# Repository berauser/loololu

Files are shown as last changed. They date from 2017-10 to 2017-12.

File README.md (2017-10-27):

# Dependencies

The project loolou depends on the avr-gcc and avrdude.

## Ubuntu

```
$ sudo apt-get install gcc-avr avrdude
```

# Build
## compile

```
$ make
```

## clean
```
$ make clean
```

## flash to attiny2313

```
# use default
# programmer: avrispv2
# usb device: /dev/ttyACM0
$ sudo make burn
```

```
# overwrite defaults
# AVRDUDE_PROGRAMMER override programmer type
# AVRDUDE_PORT overrides usb device
$ sudo make AVRDUDE_PROGRAMMER=avrispv2 AVRDUDE_PORT=/dev/ttyACM0 burn
```

## Useful links

* https://startingelectronics.org/tutorials/AVR-8-microcontrollers/ATtiny2313-tutorial/
* http://www.atmel.com/webdoc/avrlibcreferencemanual/index.html
* http://www.avr-tutorials.com/interrupts/avr-external-interrupt-c-programming

## Datasheet
### Attiny2313

* http://www.atmel.com/Images/Atmel-2543-AVR-ATtiny2313_Datasheet.pdf

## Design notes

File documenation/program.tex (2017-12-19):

\subsection{Spielmodis}

Die loolou Erweiterung hat vier verschiedene Modi zum Spielen. Diese k"onnen w"ahrend dem Spiel einfach "uber den Drucktaster am Oberteil der Spielbasis umgeschaltet werden.
Die vier roten LEDs neben dem Drucktaster zeigen dabei den aktuellen Modus an. \\
Die folgende Tabelle beschreibt die 4 verschiedenen Modi.

\vspace{1cm}
\begin{table}[ht]
	\centering

	\begin{tabular}{ c | p{8cm} } 
		% table header
		Modus								& Beschreibung \\ 
		\hline \hline
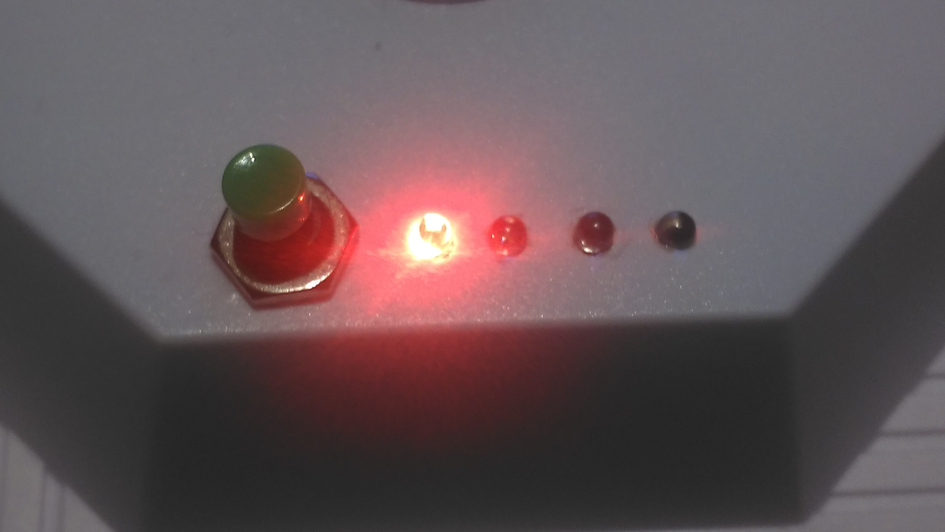
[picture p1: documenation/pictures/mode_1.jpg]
			& Einfacher Modus.\newline Looping Louie dreht sich so schnell wie beim originalen Spiel.  \\
		\hline
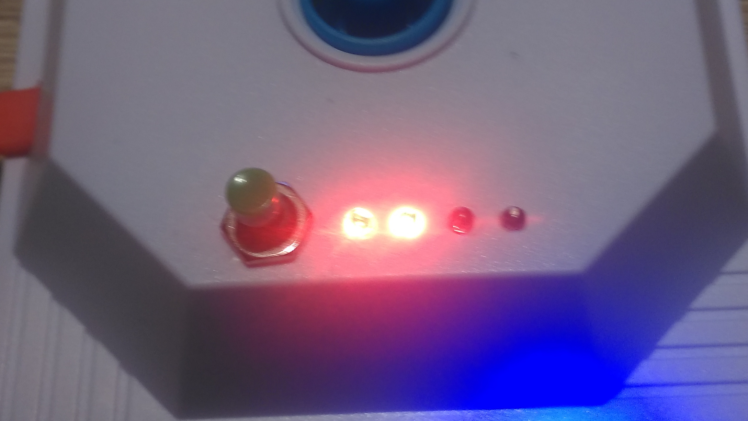
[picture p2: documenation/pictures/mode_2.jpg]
			& Schneller Modus.\newline Looping Louie dreht sich viel schneller als gewohnt. \\
		\hline
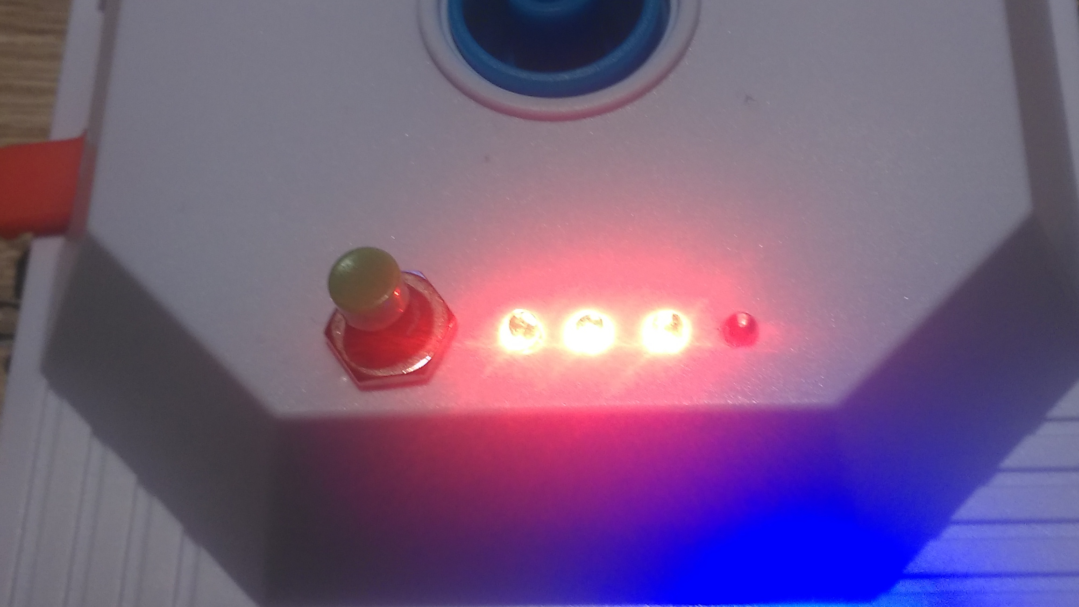
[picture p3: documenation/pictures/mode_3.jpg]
			& Zuf"alliger Modus.\newline Looping Louie "andert seine Gewschwindigkeit und bleibt auch mal stehen. \\
		\hline
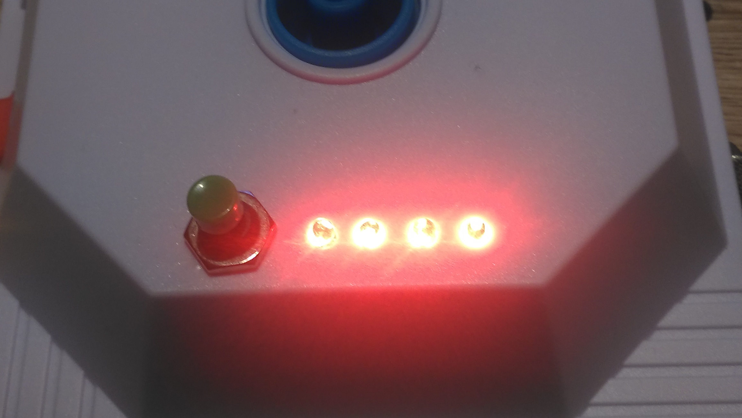
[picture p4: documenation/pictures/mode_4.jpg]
			& Zuf"alliger Modus mit R"uckw"artsgang.\newline Looping Louie "andert seine Geschwindigkeit und Richtung. \\
		\hline
	\end{tabular}

	\caption{Spielmodi}
	\label{table:mode}
\end{table}
\vspace{0.5cm}

\newpage
\subsection{Source code}

Der Source-Code von loolou ist ver"offentlich und kann heruntergeladen und selbst kompiliert werden.
Bitte beachten Sie die Lizenz von loolou. Zu finden ist diese im Kapitel ~\ref{section:licence} auf Seite ~\pageref{section:licence}.
\subsubsection{Github}\label{subsubsection:github}

Der Source-Code ist auf Github ver"offentlich und kann unter folgendem Link heruntergeladen werden. \\
\begin{center}\href{https://github.com/berauser/loolou}{https://github.com/berauser/loolou}\end{center}
\vspace{0.5cm}

\subsubsection{Defines}

Die defines sind in der Datei main.c definiert. Sie definieren die PINs und PORTs der LEDs, PWMs und des Drucktasters f"ur den ATTINY2313.
Ebenso werden hier die Timer-Delays und PWM-Frequenzen f"ur den Spielablauf definiert. Das folgende Listing (Listing ~\ref{lst:defines}) zeigt alle, f"ur den Spielablauf wichtigen, Defines. 

\vspace{0.5cm}
\begin{lstlisting}[caption={Defines},label=lst:defines]
// ********************************************************
// PWM values
// ********************************************************
#define PWM_OFF   0 // 0V ( OFF )
#define PWM_3V   85 // 3V ( (9V / 255) * 85 = 3V )
#define PWM_9V  255 // 9V

// ********************************************************
// PWM values
// ********************************************************
//
//   1000000Hz ( F_CPU )
//  --------------------- = 976,56 ( 0x3D0 )
//   1024 * 1Hz (1 sec)
#define TIMER_INT_DEPLAY 0x3D0

// ********************************************************
// Pin description
// ********************************************************
//
//		  attiny 2313
//           ---------------------
//  RESET   -| 1 (PA2)  (VCC) 20 |- VCC
//  LED5    -| 2 (PD0)  (PB7) 19 |- SCK
//  LED6    -| 3 (PD1)  (PB6) 18 |- MISO
//  LED7    -| 4 (PA1)  (PB5) 17 |- MOSI
//  LED8    -| 5 (PA0)  (PB4) 16 |- FORWARD
//  BUTTON  -| 6 (PD2)  (PB3) 15 |- BACKWARD
//  NC      -| 7 (PD3)  (PB2) 14 |- PWM
//  LED1    -| 8 (PD4)  (PB1) 13 |- LED4
//  LED2    -| 9 (PD5)  (PB0) 12 |- LED3
//  GND     -| 10(GND)  (PD6) 11 |- NC
//           --------------------
//

// *** LEDs ***********************************************
#define PIN_LED1 PD4
#define PIN_LED2 PD5
#define PIN_LED3 PB0
#define PIN_LED4 PB1
#define PIN_LED5 PD0
#define PIN_LED6 PD1
#define PIN_LED7 PA1
#define PIN_LED8 PA0

#define PORT_LED1 PORTD
#define PORT_LED2 PORTD
#define PORT_LED3 PORTB
#define PORT_LED4 PORTB
#define PORT_LED5 PORTD
#define PORT_LED6 PORTD
#define PORT_LED7 PORTA
#define PORT_LED8 PORTA

#define DDR_LED1 DDRD
#define DDR_LED2 DDRD
#define DDR_LED3 DDRB
#define DDR_LED4 DDRB
#define DDR_LED5 DDRD
#define DDR_LED6 DDRD
#define DDR_LED7 DDRA
#define DDR_LED8 DDRA

// *** DIRECTION / PWM ************************************
#define PIN_DIRECTION_FORWARD  PB4
#define PIN_DIRECTION_BACKWARD PB3
#define PIN_PWM                PB2

#define PORT_DIRECTION_FORWARD  PORTB
#define PORT_DIRECTION_BACKWARD PORTB
//#define PORT_PWM

#define DDR_DIRECTION_FORWARD  DDRB
#define DDR_DIRECTION_BACKWARD DDRB
#define DDR_PWM                DDRB

#define REGISTER_PWM  OCR0A
#define MODE_PWM      (1 << COM0A1) | (1 << WGM00)
#define CLOCK_PWM     (1 << CS01)

#define REGISTER_TIMER OCR1A
#define MODE_TIMERA    0x00
#define MODE_TIMERB    (1 << WGM12) | (1 << CS12) | (1 << CS10) // clk/1024

// *** BUTTON *********************************************
#define PIN_BUTTON  PD2
#define PORT_BUTTON PORTD
#define DDR_BUTTON  DDRD
#define EDGE_TYPE_BUTTON (1 << ISC01) // interrupt on falling egde
\end{lstlisting}
\vspace{0.5cm}

\subsubsection{Main-Methode}

Im Listing ~\ref{lst:main} ist die main-Funktion des Programmes. Diese initialisiert die Peripherie und springt dann in eine while-true-loop.
Die while-true-loop setzt in jeden Durchlauf die aktuelle Geschwindigkeit und schaltet die LEDs f"ur die Richtungsanzeige ein, beziehungsweise aus. Anschlie"send werden 250ms gewartet bis die n"achste LED f"ur die Richtungsanzeige eingeschaltet wird. 

\vspace{0.5cm}
\begin{lstlisting}[caption={Main-Method},label=lst:main]
// ****************************************************************************
// game
// ***************************************************************************/
int main(void) {

	init();
	setup();

	/* main loop */
	while (1) {
		/* all other uses interrupts */
		trigger_speed( speed );
		trigger_direction( direction );
		show_direction( direction );
		_delay_ms( 250 );
	}

	return 0;
}
\end{lstlisting}
\vspace{0.5cm}

\subsubsection{Init-Methode}

Die Methode init initialisert die GPIOs (General Porpuse Input/Output) des ATTINY.

\vspace{0.5cm}
\begin{lstlisting}[caption={Setup-Method},label=lst:setup]
// ****************************************************************************
// initialize gpio, set pin directions
// ***************************************************************************/
void init( void )
{
	// leds
	GPIO_init( DDR_LED5, PIN_LED5, OUTPUT ); // 1
	GPIO_init( DDR_LED6, PIN_LED6, OUTPUT ); // 2
	GPIO_init( DDR_LED7, PIN_LED7, OUTPUT ); // 3
	GPIO_init( DDR_LED8, PIN_LED8, OUTPUT ); // 4

	GPIO_init( DDR_LED1, PIN_LED1, OUTPUT ); // red
	GPIO_init( DDR_LED2, PIN_LED2, OUTPUT ); // blue
	GPIO_init( DDR_LED3, PIN_LED3, OUTPUT ); // green
	GPIO_init( DDR_LED4, PIN_LED4, OUTPUT ); // yellow

	// motor control
	GPIO_init( DDR_DIRECTION_BACKWARD, PIN_DIRECTION_BACKWARD, OUTPUT ); // backward
	GPIO_init( DDR_DIRECTION_FORWARD,  PIN_DIRECTION_FORWARD,  OUTPUT ); // forward
	GPIO_init( DDR_PWM, PIN_PWM, OUTPUT ); // PWM
	PWM_enable( MODE_PWM, CLOCK_PWM, REGISTER_PWM, PWM_OFF );

	// button
	GPIO_init( DDR_BUTTON, PIN_BUTTON, INPUT);
	GPIO_interrupt( PORT_BUTTON, PIN_BUTTON, INT0, EDGE_TYPE_BUTTON );

	// timer interrupt
	TIMER_enable( MODE_TIMERA, MODE_TIMERB );

	// Enable interrupts
	sei();
}
\end{lstlisting}
\vspace{0.5cm}

\subsubsection{Setup-Methode}

Die Setup-Methode initialisert das loolou-Programm mit den default-Werten.

\vspace{0.5cm}
\begin{lstlisting}[caption={Init-Method},label=lst:init]
// ****************************************************************************
// setup syStem with default values
// ***************************************************************************/
void init( void )
{
	// set initial values
	active_led  = LED1;
	mode        = M_NORMAL_FORWARD;
	speed       = PWM_3V;
	direction   = FORWARD;

	// show current mode
	show_mode();

	// set seed
	init_random( TCNT1L );

	// initial pwm
	trigger_speed( PWM_3V );

	// set initial timer delay
	TIMER_set( TIMER_INT_DEPLAY );
}
\end{lstlisting}
\vspace{0.5cm}

\subsubsection{Interrupt Service Routine}

Das Programm loolou implementiert zwei verschiedene Interrupt Service Routinen (ISR) - die ISR(INT0\_vect) und ISR(TIMER1\_COMPA\_vect). \\
Die ISR(INT0\_vect) wird bei einer fallenden Flanke am Drucktaster aufgerufen. In der ISR(INT0\_vect) wird der Modus des Spieles um eins hochgez"ahlt und neu ausgegeben. Anschlie"send wird der Timer zur"uckgesetzt und aufgerufen um die neue Geschwindigkeit und Spiel-Richtung zu setzen. \\
Die Interrupt Service Routine ISR(TIMER1\_COMPA\_vect) wird jede Sekunde aufgerufen und berechnet die Geschwindigkeit und die Spiel-Richtung neu.

\vspace{0.5cm}
\begin{lstlisting}[caption={Interrupt Service Routine},label=lst:isr]
// ****************************************************************************
// interrupt service routine
// ***************************************************************************/
ISR(INT0_vect)
{
	ADD_ONE_BETWEEN( mode, M_NORMAL_FORWARD, M_RANDOM_RANDOM );
	show_mode();

	/* reset timer, call ISR to change speed/direction immediately */
	TIMER_reset();
	TIMER1_COMPA_vect();
}

ISR(TIMER1_COMPA_vect)
{
	direction = calc_direction();
	speed = calc_speed();
}
\end{lstlisting}
\vspace{0.5cm}

\subsubsection{Calculate direction Methode}

Die Funktion calc\_direction gibt anhand des aktuellen Spielmodus die Spiel-Richtung zur"uck.
F"ur die drei Spielmodis \grqq{}Einfacher Modus\grqq{}, \grqq{}Schneller Modus\grqq{} und \grqq{}Zuf"alliger Modus\grqq{} wird immer die Spiel-Richtung \grqq{}forw"arts\grqq{} ausgeben.
Im Spielmodus \grqq{}Zuf"alliger Modus mit R"uckw"artsgang\grqq{} wird anhand einer Zufallszahl die Spiel-Richtung berechnet. In diesem Modus wird etwa 10\% \grqq{}r"uckw"arts\grqq{} und etwa 90\% \grqq{}forw"arts\grqq{} zur"uckgegeben.

\vspace{0.5cm}
\begin{lstlisting}[caption={Calculate direction},label=lst:calcdirection]
// ****************************************************************************
// calculates a new direction
// ***************************************************************************/
GameDirection calc_direction( void )
{
	switch( mode )
	{
		case M_NORMAL_FORWARD:
		case M_FAST_FORWARD:
		case M_RANDOM_FORWARD:
		default:
			return FORWARD;
			break;
		case M_RANDOM_RANDOM:
			return ( (get_random_between( 0, 10 ) == 0) ? BACKWARD : FORWARD ); /* 10% backward : 90% forward */
			break;
	}
}
\end{lstlisting}
\vspace{0.5cm}

\subsubsection{Calculate speed Methode}

Die Funktion calculate\_speed gitb anhand des Spielmodus die berechnete Geschwindigkeit zur"uck.
Im Modus \grqq{}Einfacher Modus\grqq{} wird immer der PWM-Wert f"ur 3V und im Modus \grqq{}Schneller Modus\grqq{} der PWM-Wert f"ur 9V zur"uckgeliefert.
In den Spielmodis \grqq{}Zuf"alliger Modus\grqq{} und \grqq{}Zuf"alliger Modus mit R"uckw"artsgang\grqq{} wird die Geschwindigkeit anhand zweier Zufallszahlen berechnet.
Dabei wird die erste Zufallszahl f"ur die grobe Einordnung der Geschwindigkeit verwendet und die zweite Zufallszahl f"ur die exakten PWM-Wert, der dann auch zur"uckgegeben wird. Die erste Zufallszahl ist in dieser BErechnung notwendig um gr"o"sere Spr"unge zwischen den Geschwindigkeiten zu reduzieren. 
Die Werte sind wie folgt aufgeteilt: Etwa 10\% zwischen 0.0V und \~{}3.5V, etwa 70\% zwischen \~{}3.5V und \~{}7.0V, sowie 20\% zwischen \~{}7.0V und \~{}9.0V. 

\vspace{0.5cm}
\begin{lstlisting}[caption={Calculate Speed},label=lst:calcspeed]
// ****************************************************************************
// calculates a new speed
// ***************************************************************************/
uint8_t calc_speed( void )
{
	switch( mode )
	{
	case M_NORMAL_FORWARD:
	default:
		return PWM_3V;
		break;
	case M_FAST_FORWARD:
		return PWM_9V;
		break;
	case M_RANDOM_FORWARD:
	case M_RANDOM_RANDOM:
	{
		/*
		 * Calculate speed in 25 steps.
		 * 0 = 0V, ...,  25 = ~9V
		 *
		 * For a better and faster playing pleasure,
		 * a probability of
		 * 10% values between   0V and 3,5V and
		 * 70% values between 3,5V and 6,0V is selected.
		 * 20% values between 7,0V and 9,0V is selected.
		 */
		static uint8_t r = 0;
		r = get_random_between( 0, 10 );
		if ( r == 0 )
		{ /* 20% slow ( 0V - ~3,5V ) */
			return get_random_between(  0, 100 );
		}
		else if ( r == 1 || r == 2 )
		{ /* 20% very fast /~7,0V - 9,0V */
			return get_random_between( 201, 255);
		}
		else
		{ /* 70% fast ( ~3,5V - ~7,0V ) */
			return get_random_between( 101, 200 );
		}
	}
		break;

	}
}
\end{lstlisting}
\vspace{0.5cm}

\subsection{Kompilieren des Sourcecodes}
\subsubsection{Abh"angigkeiten an das Buildsystem}

Um den C-Sourcecode f"ur den ATTINY2313 zu "ubersetzen werden einige wenige Anfoderungen an das Buildsystem gestellt.
Es wir lediglich die AVR-Toolchain (avr-gcc) und ein Programmer f"ur Atmel-Mikrocontroller ben"otigt (avrdude).
Um die Dokumentation zu erstellen wird zus"atzlich ein LaTeX-Kompiler ben"otigt, unter Ubuntu oder Debian bietet sich hier zum Beispiel texlive an.\\
\\
F"ur Ubuntu und Debian k"onnen die folgenden Befehle, zum installieren der Abh"angigkeiten, verwendet werden.

\vspace{0.5cm}
\begin{lstlisting}[caption={Build dependencies},language=sh,label=lst:builddep]
# install avr toolchain and avr programmer
sudo apt-get install gcc-avr avrdude
# install LaTeX-Compiler
sudo apt-get install texlive-full
\end{lstlisting}
\vspace{0.5cm}

\subsubsection{Kompilieren}

Das Kompilieren des C-Sourcecodes durch einen einfachen Make-Aufruf angesto"sen werden.
Dazu muss im Root-Verzeichniss des Sourcecodes folgender Befehl eingegeben werden.

\vspace{0.5cm}
\begin{lstlisting}[caption={Compile},language=sh,label=lst:makeall]
# compile loolou
make
\end{lstlisting}
\vspace{0.5cm}

\subsubsection{Aufr"aumen}

Um die Kompilierten Source wieder zu l"oschen kann der folgende Befehl verwendet werden.

\vspace{0.5cm}
\begin{lstlisting}[caption={Clean},language=sh,label=lst:makeclean]
# clean loolou sources
make clean
\end{lstlisting}
\vspace{0.5cm}

\subsubsection{Erstellen der Dokumentation}

Das erstellen der Dokumentation kann ebenso wie das kompilieren des Sourcecodes durch einen Make-Aufruf ausgef"uhrt werden.
Dazu f"ugt man das Schl"usselwort \grqq{}doc\grqq{} dem \grqq{}make\grqq{} an.

\vspace{0.5cm}
\begin{lstlisting}[caption={Create documentation},language=sh,label=lst:builddoc]
# create documenation
make doc
# clean documenation
make doc-clean
\end{lstlisting}
\vspace{0.5cm}

\subsection{Wie der Attiny2313 programmiert wird}
\subsubsection{Programming}

Ebenso wie das Kompilieren der Source kann der Attiny mittels eines vordefinierten Make-Aufrufs programmiert werden.
Dies kann "uber den Befehl \grqq{}make burn\grqq{} ausgef"uhrt werden.
Mittels den Variablen \textbf{AVRDUDE\_PROGRAMMER} und \textbf{AVRDUDE\_PORT} kann das Device und der Programmer-Typ definiert werden.
Die Default-Einstellungen sind \textbf{avrispv2} f"ur den Typ des Programmers und \textbf{/dev/ttyAMC0} f"ur das Device.
Der Typ des Programmers kann der Dokumentation des Programmers entnommen werden. \\
\\
\textbf{Achtung: Sollte der Programmer eine eigene Stromversorgung f"ur den Attiny haben, dann darf der 9V Stromanschluss des Looping Louie nicht angeschlossen werden}, wenn das Programmieren "uber die eingebaute Programmier-Schnittstelle (J1) stattfindet. Andernfalls kann der Programmer besch"adigt werden.

\vspace{0.5cm}
\begin{lstlisting}[caption={Programming},language=sh,label=lst:makeburn]
# flash the attiny (using default values)
make burn
# or
make AVRDUDE_PROGRAMMER=avrispv2 AVRDUDE_PORT=/dev/ttyAMC0 burn
# AVRDUDE_PROGRAMMER define programmer type
# AVRDUDE_PORT define programmer device
\end{lstlisting}
\vspace{0.5cm}

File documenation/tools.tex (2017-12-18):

F"ur den Umbau von Looping Louie werden diverse Werkzeuge ben"otigt. Diese sind in Tablle ~\ref{table:tools} aufgelistet.

\vspace{1cm}
\begin{table}[ht]
	\centering

	\begin{tabular}{ c p{8cm} } 
		% table header
		\hline \hline
			& Schraubenzieher (Kreuzschlitz) \\
			& Akkuschrauber                  \\
			& Bohrer (3/5/7/8mm)             \\
			& B"ugels"age                    \\
			& Feile                          \\
			& Zange                          \\
			& Seitenschneider                \\
			& L"otkolben                     \\
		\hline \hline
	\end{tabular}

	\caption{Werkzeuge}
	\label{table:tools}
\end{table}
\vspace{0.5cm}

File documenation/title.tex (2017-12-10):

\maketitle
\vspace{3cm}
\begin{figure}[!ht]
	\centering
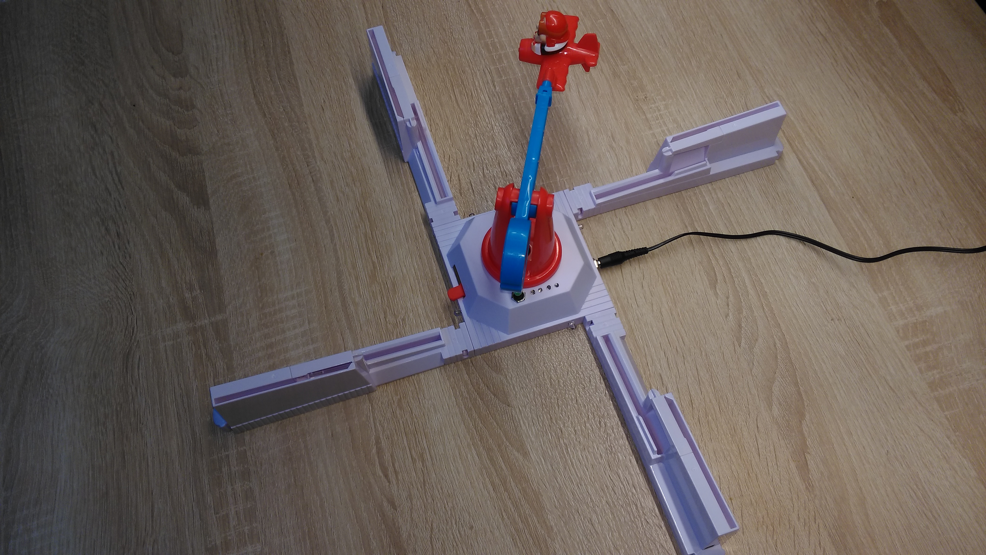
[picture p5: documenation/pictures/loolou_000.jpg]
  	
	\caption{Looping Louie mit loolou Erweiterung}
	\label{fig:loolou}
\end{figure}

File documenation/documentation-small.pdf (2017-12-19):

# loolou

Looping Louie Erweiterung

Benjamin Rauser

19. Dezember 2017

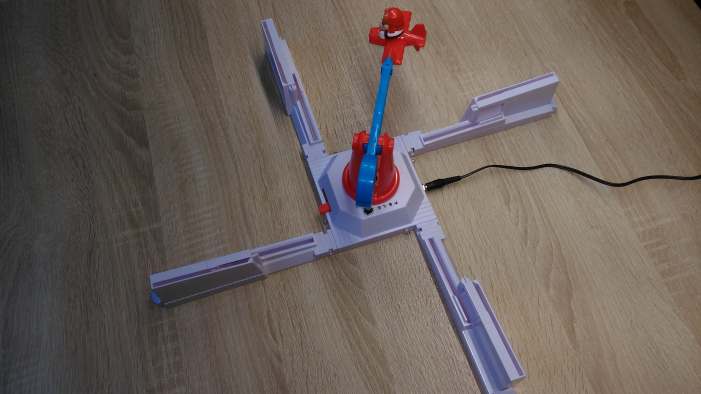
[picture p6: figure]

Abbildung 1: Looping Louie mit loolou Erweiterung

1

### Inhaltsverzeichnis

1. Motivation | 3
2. Werkzeug | 4
3. Hinweise | 4
4. Changelog | 5
5. Anleitung | 6
6. Programm | 19
7. Komponenten | 28
8. Lizenz | 30
9. Haftungsausschluss | 30
10.Anhang | 32
A. Layout | 33
B. Schaltplan | 34
C. Template | 35

2

### 1. Motivation

Intrinsisch

3

### 2. Werkzeug

Fur den Umbau von Looping Louie werden diverse Werkzeuge ben ¨ | ötigt. Diese sind in Tablle 1
aufgelistet.

Schraubenzieher (Kreuzschlitz) Akkuschrauber
Bohrer (3/5/7/8mm)
Bugels ¨ äge
Feile
Zange
Seitenschneider
Lötkolben

Tabelle 1: Werkzeuge

### 3. Hinweise

### 3.1. Revision 1

- Das Loch fur den Drucktaster und der Befestigungsschraube sind zu klein. D ¨ | iese sollte vorsichtig
aufgebohrt werden.

4

### 4. Changelog

### 4.1. Revision 1

- Erstellen des Schaltplanes.
- Erstellen des C-Quellcodes.
- Erstellen des Platinen-Layouts.
- Erstellen der Dokumentation.
- Hinzufugen von Fotos. ¨

5

### 5. Anleitung

### 5.1. Spielbasis

Zeitaufwand: 8h

Als erstes widmen wir uns der Spielbasis, zu sehen in Abbildung 2. Sie muss im ersten Schritt zerlegt und angepasst werden, um Platz fur die Platine zu schaffen. ¨

Dazu entfernen wir als erstes die 7 Schrauben an der Unterseite.
Die ersten 5 Schrauben sind mit bloßem Auge von aussen sichtbar. Die letzten zwei Schrauben sind nach dem öffnen des Batteriefaches zu sehen.

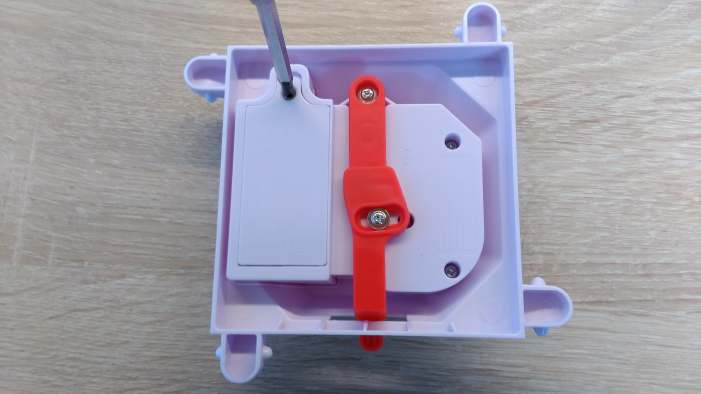
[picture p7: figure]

Abbildung 2: Spielbasis - Unterseite aufschrauben

Abbildung 3 zeigt die Spielbasis nach dem entfernen der 7 Schrauben.

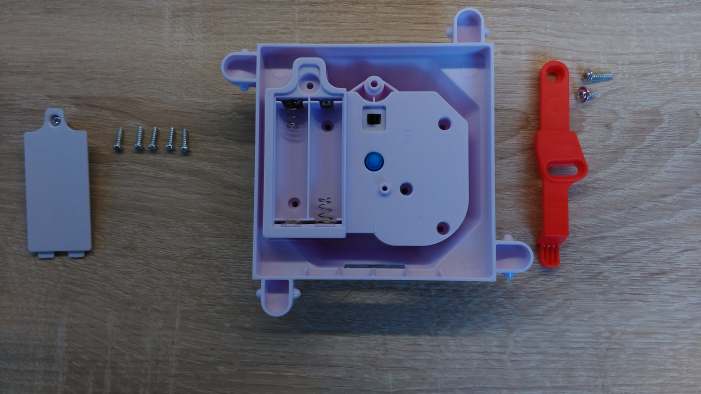
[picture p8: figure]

Abbildung 3: Spielbasis - geöffnet

6

Anschließend muss die Spielbasis geöffnet werden. Dazu zieht man das Innenteil der Spielbasis heraus. Zu sehen ist nun das Getriebe, der Motor und der Stromschalter (siehe Abbildung 4 und 5).

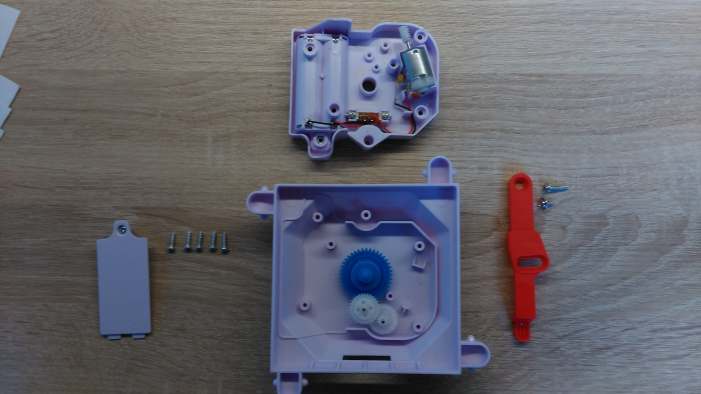
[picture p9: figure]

Abbildung 4: Spielbasis - geöffnet

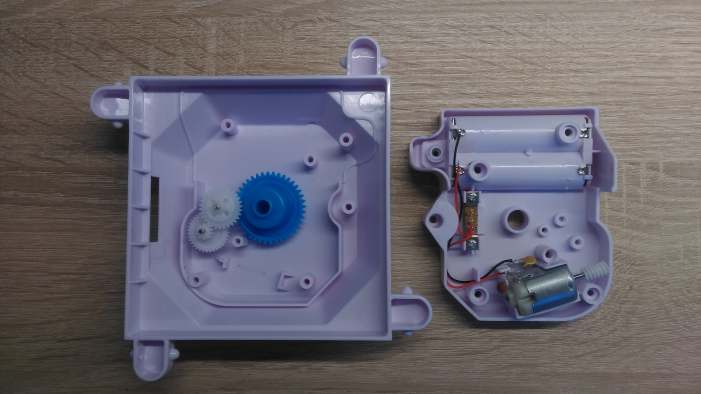
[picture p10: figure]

Abbildung 5: Spielbasis - Abdeckung

Nun muss der Motor, der Stromschalter und die Batteriekontakte entfernt werden.
Am besten löst man hierfur zuerst die Stromkabel, mit einem L ¨ | ötkolben, von den Batteriekontakten.
Anschließend kann der Motor ganz einfach herausgezogen und der Stromschalter mittels eines Schraubenziehers entfernt werden. Danach können die Batteriekontakte mit einer Zange herausgezogen werden. Abbildung 6 zeigt die Abdeckung der Spielbasis ohne Motor, Stromschalter und Batteriekontakte.

Als nächstes muss Platz fur die Platine geschaffen werden. ¨
Dazu bohrt man an den 4 Ecken des Batteriefaches jeweils ein Loch und sägt mit einer Säge am Rand

7

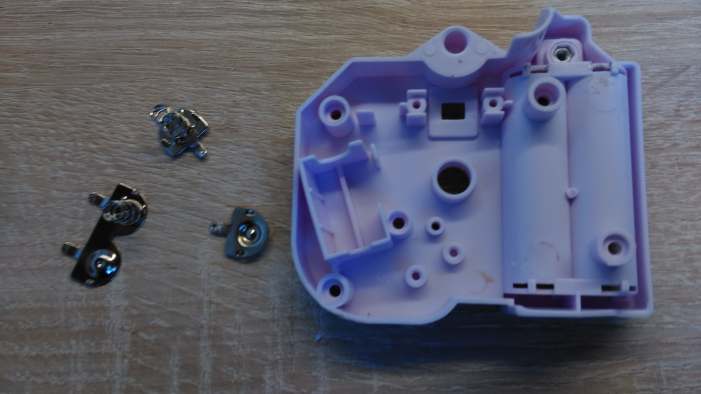
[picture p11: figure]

Abbildung 6: Spielbasis - Unterseite Abdeckung ohne Motor und Batteriekontakten

des Batteriefaches entlang (zu sehen in Abbildung 7).
Achte an dieser Stelle besonders auf das Gehäuse - Es sollte nicht brechen bzw. es sollte nicht weiter als die Umrandung des Batteriefach gesägt werden. Ansonsten sieht man beim späteren Zusammenbau
der Spielbasis die Schnitte der Säge. Ebenso sollten keine Gewinde fur die Schrauben abges ¨ | ägt werden,
mit Ausnahme der Gewinde im Batteriefach. Fur die feineren Arbeiten kann eine Feile benutzt werden. ¨ Anschlieend muss in den herausstehenden Seiten jeweils eine Ecke herausgefeilt werden (Gut zu sehen in der Abbildung 8). Diese werden später benötigt um die Stromkabel fur die LEDs und des Netzteils ¨ aus der Spielbasis herauszufuhren. ¨

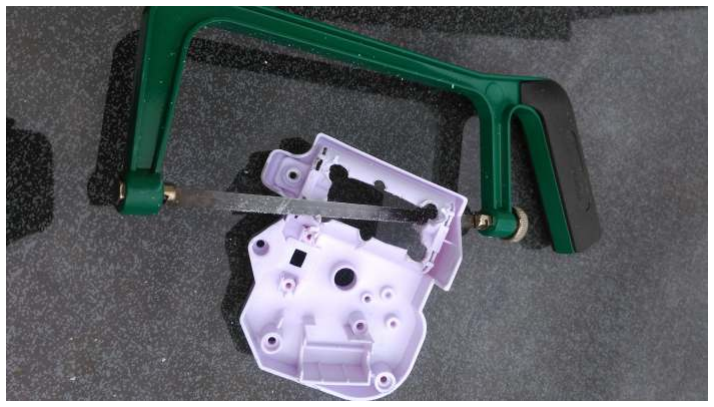
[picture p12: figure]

Abbildung 7: Spielbasis - Unterseite beim Aussägen

Abbildung 8 zeigt die fertig vorbereitete Unterseite der Spielbasis. Gut zu sehen sind hier die
abgefeilten Ecken fur die Stromkabel und das ausges ¨ | ägte Batteriefach. Wichtig an dieser Stelle ist
auch, dass das Batteriefach vollstäntig entfernt und bis auf den letzten Millimeter abgefeilt wurde. Ansonsten kann es vorkommen, dass das Gehäuse beim späteren Zusammenbau nicht richtig schließt.

8

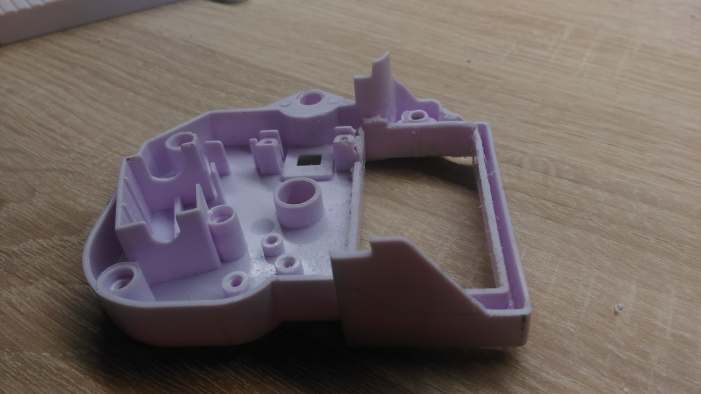
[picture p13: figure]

Abbildung 8: Spielbasis - Unterseite ausgesägt und geschliffen

Nun kann die Unterseite der Spielbasis zur Seite gelegt werden. Es folgt die Vorbereitung der Oberseite.
Als erstes sollte hier das Gewinde im linken oberen Eck (siehe Abbildung 9) mit einem Bohrer entfernt werden. Dieses Gewinde ist der Platine im Weg und muss daher entfernt werden. Achte hierbei darauf das nicht durch das Oberteil gebohrt wird, lasse lieber ein bis zwei Millimeter uberstehen. ¨

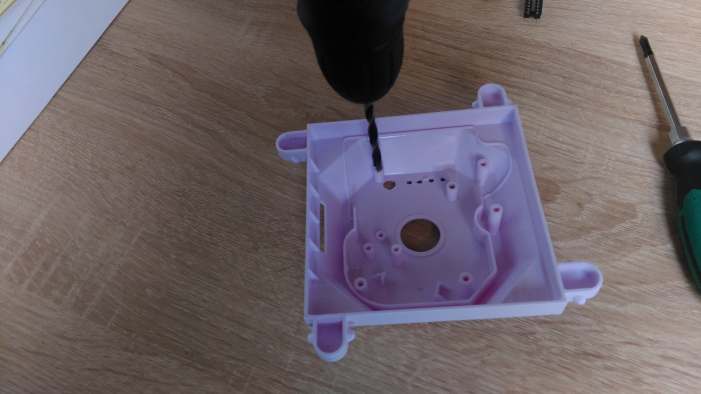
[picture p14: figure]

Abbildung 9: Spielbasis - Oberseite mit Gewinde das entfernt werden muss

Als nächstes schneidet man zuerst die Schablonen (siehe Anhang 10) aus. Diese werden benötigt
um die Löcher fur die LEDs, den Taster und den Stromanschluß richtig zu positionie ¨ | ren. Abbildung
10 zeigt die Schablonen und das fertig Vorbereitete Gehäuse.

Im nächsten Schritt nimmt man den große ausgeschnitten Teil der Schablone und legt ihn auf die

9

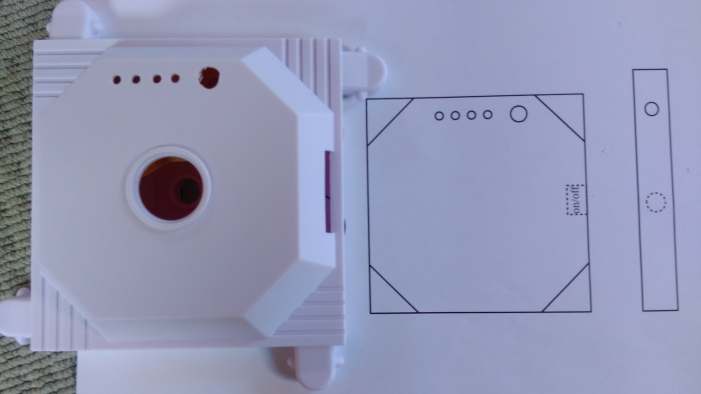
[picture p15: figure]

Abbildung 10: Schablonen und Oberteil der Spielbasis

Oberseite der Spielbasis. Man sollte hier darauf achten dass die Schrift “on/off“ uber dem AN/AUS- ¨ Schalter der Spielbasis liegt (zu sehen in Abbildung 11). Anschließend können zuerst mit einem spitzen Gegenstand (zum Beispiel einem Bohrer) die Löcher auf dem Oberteil der Spielbasis angekörnt werden.
Die kleinen Löcher, fur die LEDs, werden nun mit einem 3mm-Bohrer durchbohrt. Im Anschl ¨ | uss wird
das Loch fur den Drucktaster mit einem 7mm-Bohrer in das Oberteil gebohrt. Abb ¨ | ildung 11 zeigt
die gebohrten Löcher in dem Oberteil der Spielbasis. Zu sehen ist hier auch dass die Löcher auf der rechten Seite, vom AN/AUS-Schalter aus gesehen, liegen.

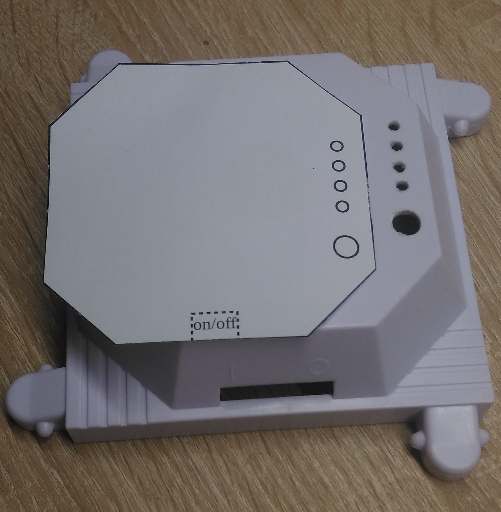
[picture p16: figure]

Abbildung 11: Spielbasis - Gebohrte Löcher fur die LEDs und den Taster im Oberteil ¨

10

Nun nimmt man das kleine rechteckige Teil der Schablone und körnt damit an jeder der 4 Seiten
das Loch fur die 5mm großen LEDs an (Kreis mit durchgezogener Linie). Dabei muss der ¨ | Kreis mit
der durchgezogenen Linie zu dem Verbindungsstuck, f ¨ | ur die Arme des Looping Louie, zeigen (zu sehen ¨
in Abbildung 12). Der gestrichelte Kreis ist fur den Stromanschluss. Dieser wird auf der, dem des ¨
AN/AUS-Schalter gegebuberliegenden Seite, gebohrt (zu sehen in Abbildung 12). Die L ¨ | öcher fur die ¨
LEDs werden mit einem Bohrer der Stärke von 5mm und das Loch fur den Stromanschluss mit einen ¨ 7mm großen Bohrer gebohrt.

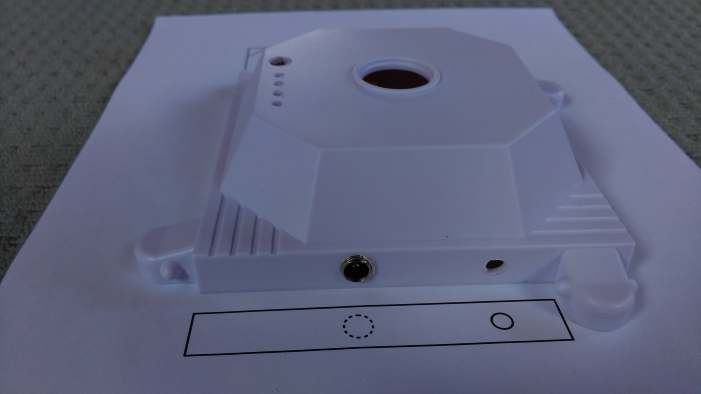
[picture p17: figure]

Abbildung 12: Spielbasis - Mit gebohrten Löchern in der Seite des Oberteils

Zum Abschluss können nun noch alle LEDs, der Drucktaster und der Stromanschluss in die Spielbasis gesteckt werden. Sollte hier noch etwas klemmen kann an dieser Stelle noch leicht nachgearbeitet werden.

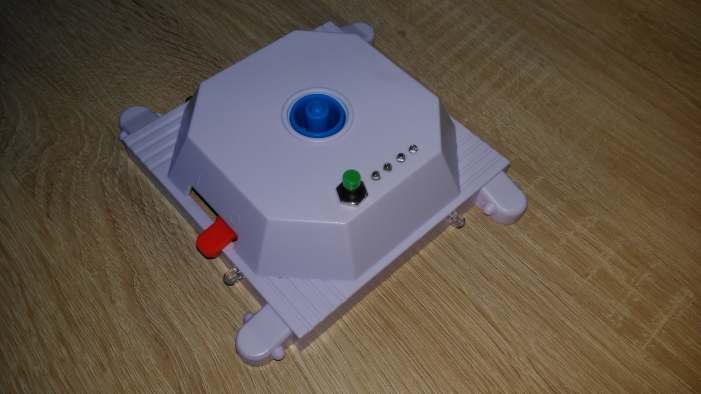
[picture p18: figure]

Abbildung 13: Spielbasis - Mit gesteckten LEDs, dem Drucktaster und dem Stromanschluss

11

Die Abbildung 13 zeigt die Spielbasis mit den gesteckten LEDs, dem Drucktaster und dem Stromanschluss. Die Bauteile können nun wieder aus der Spielbasis entfernt und zur Seite gelegt werden.

12

### 5.2. Platine

Nun widmen wir uns der Platine - dem Herzstuck der Erweiterung von Looping Louie. Zu sehen ist ¨ diese in den Abbildungen 14 (a) und (b).

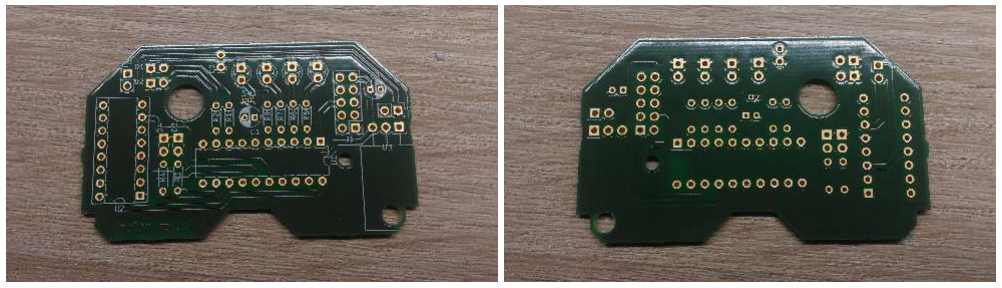
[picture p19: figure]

(a) Oberseite | (b) Unterseite

Abbildung 14: Originale Platine - Revision 1

Auf der Platine sind unteranderem ein kleiner Microcontroller (ATTINY2313), ein Treiberbaustein, ein Festspannungsregler sowie diverse LEDs und Widerstände verbaut. Der Schaltplan 10 und das Platinen-Layout 10 kann im Anhang gefunden werden. Die Referenzen der Bauteile können der Tabelle 4 entnommen werden.

Am einfachsten beginnt man an dieser Stelle mit den IC-Sockeln (U1 und U2), sowie dem Festspan-
nungsregler (U3). Im Anschluss kann der 10polige Wannenstecker (J1), fur den Programmer, aufgel ¨ | ötet
werden, dieser ist optional und wird nur benötigt wenn man den Attiny zum programmieren nicht herausnehmen möchte. Nachdem die IC-Sockel und der Festspannungsregler aufgelötet wurden, können die Widerstände (R1-R8) und die Kondensatoren (C1-C3) aufgelötet werden. Die Abbildung 15 zeigt die Platinen nach dem auflöten der Widerstände, der Kondensatoren, dem Festspannungsregler und den IC-Sockeln.

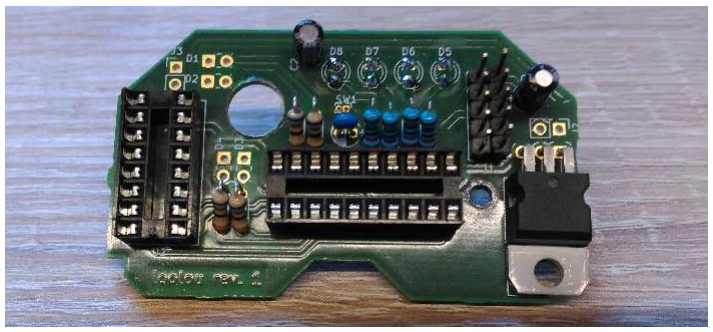
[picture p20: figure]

Abbildung 15: Platine mit aufgelöteten Widerständen und IC-Sockel

13

Nachdem nun die IC-Sockel (U1,U2), der Festspannungsregler (U3), die Widerstände (R1-R8) und die Kondensatoren (C1-C3) aufgelötet wurden, sollten die LEDs (D5-D8) aufgelötet werden. Dazu steckt man diese einzeln, von innen, in das Oberteil der Spielbasis und schraubt dann die Platine in
den dafur vorgesehenen Platz im Oberteil der Spielbasis. Wie die Platine ¨ | in das Oberteil der Spielbasis
geschraubt wird zeigt die Abbildung 16
Nachdem nun die LEDs in die Spielbasis gesteckt und die Drähte der LEDs (D5-D8) durch die dafur ¨
vorgsehenen Löcher gefuhrt wurden, k ¨ | önnen diese an der Platine festgelötet werden. Achte an dieser
Stelle darauf das die LEDs richtig gepolt sind, ansonsten mussen diese sp ¨ | äter wieder entfernt und neu
aufgelötet werden.

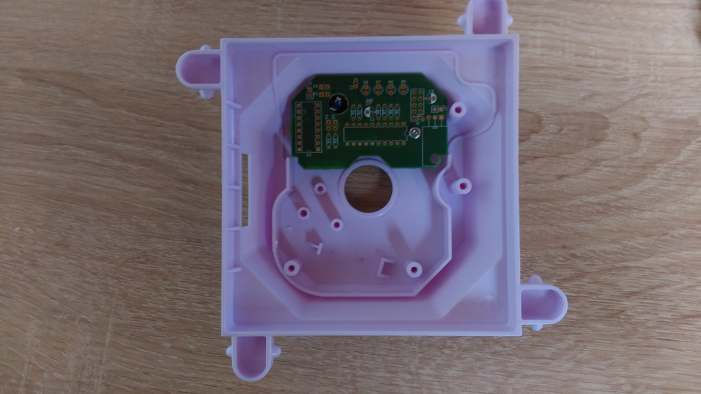
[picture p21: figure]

Abbildung 16: Platine festgeschraubt im Oberteil der Spielbasis

Nachdem nun auch die LEDs D5 bis D8 aufgelötet sind kann die Platine nun wieder aus der Spielbasis herausgenommen werden. Die Abbildung 17 zeigt die Platine mit den festgelöteten LEDs (D5-D8). Es empfiehlt sich an dieser Stelle die bisher festgelöteten Bauteile und die Lötstellen mit einem Durch-
gangsprufer zu testen, um kalte L ¨ | ötstellen und verpolte LEDs rechtzeitig zu erkennen.

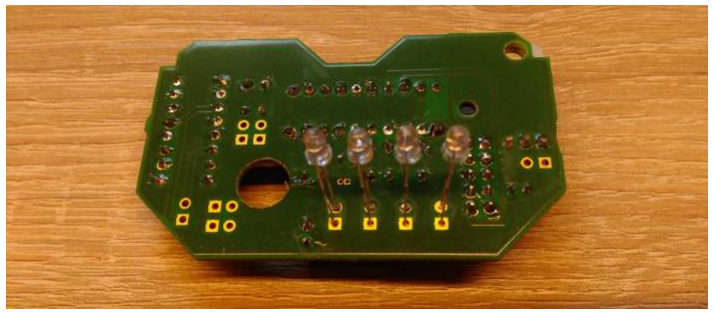
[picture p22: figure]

Abbildung 17: Platine mit LEDs auf der Unterseite

14

An dieser Stelle sollten die Litzen fur die restlichen LEDs (D1-D4), den Drucktaster (SW1), den ¨ Hohlstecker-Buchse (J2) und den Motor vorbereitet werden. Die Länge der Litzen kann einfach der Tabelle 2 entnommen werden. Es werden jeweils eine rote und eine schwarze Litze benötigt.

Reference | Description | Length
D1 | LED1, 5mm | 9cm
D2 | LED2, 5mm | 13cm
D3 | LED3, 5mm | 13cm
D4 | LED4, 5mm | 13cm
SW1 | Drucktaster | 5cm
J1 | Hohlstecker-Buchse | 7cm
J3 | Motor | 16cm

Tabelle 2: Litzenlänge

Sobald diese vorbereitet wurden, können die Litzen bereits an die LEDs (D1-D4) gelötet werden. Dazu schneidet man am Besten die Drähte der LEDs auf einen Zentimeter herunter und lötet dann die Kabel an. Im Anschluss sollten noch die offenen Lötstellen mit einem Schrumpfschlauch verschlossen werden. Anschließend können auch die Litzen an den Drucktaster und die Hochstecker-Buchse gelötet und mit einem Schrumpfschlauch verschlossen werden.
Das Pin-Layout, der Hohlstecker-Buchse, kann dem Datenblatt entnommen werden. Fur die Hohlstecker- ¨ Buchse “HEBL 21“(www.reichelt.com) ist das Pin-Layout in der Abbildung 18 zu sehen.

Abbildung 18: Pin-Layout Hohlstecker-Buchse “HEBL 21“

Die alten Litzen des Motors werden nun durch die neuen längeren Litzen ersetzt. Dabei muss die rote Litze einmal durchtrennt und wie gehabt mit dem Stromschalter verbunden werden.

Im Anschluss wird der Drucktaster mit den angelöteten Litzen, von unten in das große Loch der Platine (zwischen R2 und D2) gesteckt. Die Litzen fuhrt man dazu ebenfalls von unten nach oben ¨ durch das Loch. Die beiden Litzen (rot und schwarz) werden nun an den beiden Löchern von SW1 von oben festgelötet. Die Polung spielt hier keine Rolle.
Sobald der Drucktaster SW1 an der Platine festgelötet wurde, können die auch die LEDs (D1-D4), die Hohlstecker-Buchse (J2) und der Motor (J3) festgelötet werden. Hierbei muss auf die Polung der LEDs, der Hohlstecker-Buchse und des Motors geachtetet werden - die schwarzen Litzen (Minus-Pol)
mussen in die L ¨ | öcher mit den quadratischen Kontakten. Im Fall einer Verpolung kann es zu Schäden

15 an der Platine, zu nicht funktionierenden LEDs oder einen Motor der in die falsche Richtung dreht kommen. In der Abbildung 19 ist die fertig gelötete Platine zu erkennen (ohne Motor).

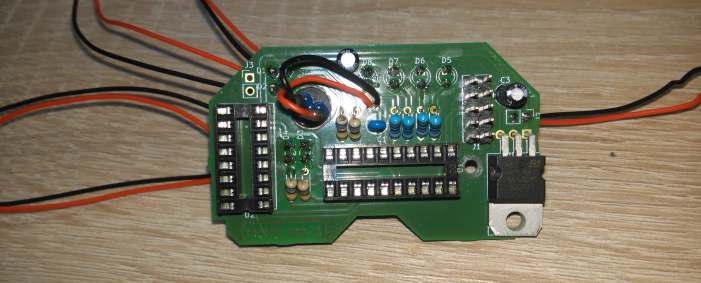
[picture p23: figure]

(a) Oberseite

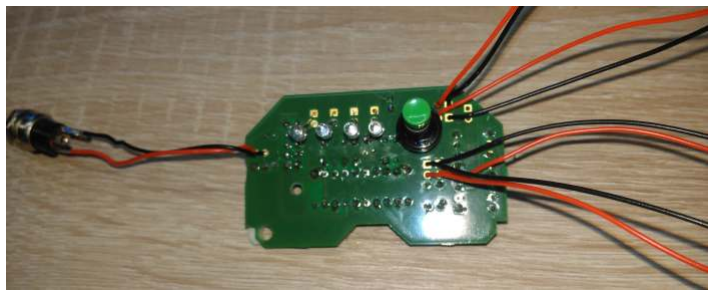
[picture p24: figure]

(b) Unterseite

Abbildung 19: Platine mit allen Bauteilen (ohne Motor)

Nun sollte die Platine nochmals mit dem Durchgangsprufer, auf kalte L ¨ | ötstellen und verpolte Bau-
teile, uberpr ¨ | uft werden. Ist hier kein Fehler zu finden, dann kann zum Testen d ¨ | as Netzteil angeschlossen
werden. Wird der Festspannungsregler schnell sehr heiß dann deutet dies auf einen Kurzschluss oder eine Verpolung hin. Weiterhin sollte zwischen den Pins 1 und 2 des Festspannungsregler eine Spannung von 9 Volt und zwischen Pin 2 und Pin 3 ein Spannung von 5V anliegen.

Im Anschluss kann der Attiny2313 und der Treiberbaustein (L293D) auf die Sockel gesteckt werden.
Die hablrunden Einkerbungen mussen daf ¨ | ur ¨ uber den weißen halbrunden Kreisen des Zeichnung (bei ¨
U1 und U2) liegen.

Steckt man nun wieder das Netzteil ein, dann sollten die LEDs D1 bis D5 abwechselnd und die LED D8 dauerhaft leuchten. Der Motor kann uber den Stromschalter, zwischen J3 und Motor, an ¨ bzw. ausgeschaltet werden. Durch den Druck auf den Drucktaster (SW1) können die LEDs D5 bis D7 getestet werden.

Ist bisher kein Fehler erkennbar, dann kann man die Platine ausschalten und zur Seite legen.

16

### 5.3. Zusammenbau

Nun werden alle Komponenten wieder zusammengebaut. Beginnen muss man beim Zusammenbau mit dem Getriebe. Dazu nimmt man das blaue Zahnrad und steckt es in das große Loch des Oberteils
der Spielbasis. Anschließend mussen die weißen Zahnr ¨ | äder eingesetzt werden. Nachdem diese eingsetzt
wurden, wird die Platine in das Oberteil geschraubt, dazu fuhrt man die Litzen der LEDs, des Motors ¨ und der Hohlstecker-Buchse an der linken bzw. rechten Seite heraus. Der Stromschalter des Motors und der Motor selbst werden wieder in die Unterseite der Spielbasis eingesetzt bzw. festgeschraubt. Wie dies am Ende aussehen muss zeigt die Abbildung 20.


Abbildung 20: Spielbasis mit eingesetzter Platine

Im Anschluss wird die Unterseite auf die Oberseite gesetzt und die 5 Schrauben der Spielbasis wieder festgeschraubt. Nun sollte man prufen, ob die Spielbasis wieder richtig schließt. Sollte beim ¨ Vorbereiten der Spielbasis nicht sauber gearbeitet worden sein, dann muss hier nochmals nachgearbeitet werden. Die Spielbasis darf keine Erhebungen aufweisen, ansonsten steht die Spielbasis nicht sicher oder der Arm des Looping Louie kann nicht richtig arretiert werden. Die Abbildung 21 zeigt die wieder zusammengebaute Spielbasis ohne Batteriefachabdeckung.


Abbildung 21: Zusammengebaute Spielbasis ohne Batteriefachabdeckung

17

In der folgenden Abbildung (Abbildung 22) ist die geschlossene Spielbasis von oben und unten zu sehen.


(a) Oberseite | (b) Unterseite

Abbildung 22: Platine mit allen Bauteilen

18

### 6. Programm

### 6.1. Spielmodis

Die loolou Erweiterung hat vier verschiedene Modi zum Spielen. Diese können während dem Spiel
einfach uber den Drucktaster am Oberteil der Spielbasis umgeschaltet wer ¨ | den. Die vier roten LEDs
neben dem Drucktaster zeigen dabei den aktuellen Modus an.
Die folgende Tabelle beschreibt die 4 verschiedenen Modi.
Modus | Beschreibung

Einfacher Modus.
Looping Louie dreht sich so schnell wie beim originalen Spiel.

Schneller Modus.
Looping Louie dreht sich viel schneller als gewohnt.

Zufälliger Modus.
Looping Louie ändert seine Gewschwindigkeit und bleibt auch mal stehen.

Zufälliger Modus mit Ruckw ¨ ärtsgang.
Looping Louie ändert seine Geschwindigkeit und Richtung.

Tabelle 3: Spielmodi

19

### 6.2. Source code

Der Source-Code von loolou ist veröffentlich und kann heruntergeladen und selbst kompiliert werden. Bitte beachten Sie die Lizenz von loolou. Zu finden ist diese im Kapitel 8 auf Seite 30.

### 6.2.1. Github

Der Source-Code ist auf Github veröffentlich und kann unter folgendem Link heruntergeladen werden.

https://github.com/berauser/loolou

### 6.2.2. Defines

Die defines sind in der Datei main.c definiert. Sie definieren die PINs und PORTs der LEDs, PWMs und
des Drucktasters fur den ATTINY2313. Ebenso werden hier die Timer-Delays und PWM-Fre ¨ | quenzen
fur den Spielablauf definiert. Das folgende Listing (Listing 1) zeigt all ¨ | e, fur den Spielablauf wichtigen, ¨
Defines.
| Listing 1: Defines

// ******************************************************** // PWM values
// ********************************************************
# define PWM_OFF | 0 // 0 V ( OFF )

# define PWM_3V | 85 // 3 V ( (9 V / 255) * 85 = 3 V )

# define PWM_9V | 255 // 9 V

// ******************************************************** // PWM values
// ******************************************************** //
// | 1000000 Hz ( F_CPU )
// | --------------------- = 976 ,56 ( 0 x3D0 )
// | 1024 * 1 Hz (1 sec )
# define TIMER_INT_DEPLAY 0 x3D0

// ******************************************************** // Pin description
// ******************************************************** //
// | attiny 2313
// | ---------------------
// | RESET | -| 1 ( PA2 ) | ( VCC ) 20 | - VCC
// | LED5 | -| 2 ( PD0 ) | ( PB7 ) 19 | - SCK
// | LED6 | -| 3 ( PD1 ) | ( PB6 ) 18 | - MISO
// | LED7 | -| 4 ( PA1 ) | ( PB5 ) 17 | - MOSI
// | LED8 | -| 5 ( PA0 ) | ( PB4 ) 16 | - FORWARD
// | BUTTON | -| 6 ( PD2 ) | ( PB3 ) 15 | - BACKWARD
// | NC | -| 7 ( PD3 ) | ( PB2 ) 14 | - PWM
// | LED1 | -| 8 ( PD4 ) | ( PB1 ) 13 | - LED4
// | LED2 | -| 9 ( PD5 ) | ( PB0 ) 12 | - LED3
// | GND | -| 10( GND ) | ( PD6 ) 11 | - NC
// | --------------------
//

20

// *** LEDs *********************************************** # define PIN_LED1 PD4
# define PIN_LED2 PD5

# define PIN_LED3 PB0

# define PIN_LED4 PB1

# define PIN_LED5 PD0

# define PIN_LED6 PD1

# define PIN_LED7 PA1

# define PIN_LED8 PA0

# define PORT_LED1 PORTD

# define PORT_LED2 PORTD

# define PORT_LED3 PORTB

# define PORT_LED4 PORTB

# define PORT_LED5 PORTD

# define PORT_LED6 PORTD

# define PORT_LED7 PORTA

# define PORT_LED8 PORTA

# define DDR_LED1 DDRD

# define DDR_LED2 DDRD

# define DDR_LED3 DDRB

# define DDR_LED4 DDRB

# define DDR_LED5 DDRD

# define DDR_LED6 DDRD

# define DDR_LED7 DDRA

# define DDR_LED8 DDRA

// *** DIRECTION / PWM ************************************ # define PIN_DIRECTION_FORWARD PB4
# define PIN_DIRECTION_BACKWARD PB3

# define PIN_PWM | PB2

# define PORT_DIRECTION_FORWARD | PORTB

# define PORT_DIRECTION_BACKWARD PORTB // # define PORT_PWM

# define DDR_DIRECTION_FORWARD DDRB # define DDR_DIRECTION_BACKWARD DDRB

# define DDR_PWM | DDRB

# define REGISTER_PWM | OCR0A

# define MODE_PWM | (1 << COM0A1 ) | (1 << WGM00 )

# define CLOCK_PWM | (1 << CS01 )

# define REGISTER_TIMER OCR1A

# define MODE_TIMERA | 0 x00

# define MODE_TIMERB | (1 << WGM12 ) | (1 << CS12 ) | (1 << CS10 ) // clk /1024

// *** BUTTON *********************************************
# define PIN_BUTTON PD2

# define PORT_BUTTON PORTD

# define DDR_BUTTON DDRD

# define EDGE_TYPE_BUTTON (1 << ISC01 ) // interrupt on falling egde

### 6.2.3. Main-Methode

Im Listing 2 ist die main-Funktion des Programmes. Diese initialisiert die Peripherie und springt dann in eine while-true-loop. Die while-true-loop setzt in jeden Durchlauf die aktuelle Geschwindigkeit und

21

schaltet die LEDs fur die Richtungsanzeige ein, beziehungsweise aus. Anschließend we ¨ | rden 250ms
gewartet bis die nächste LED fur die Richtungsanzeige eingeschaltet wird. ¨

Listing 2: Main-Method

// **************************************************************************** // game
// ***************************************************************************/ int main ( void ) {

init () ;
setup () ;

/* main loop */
while (1) {
/* all other uses interrupts */ trigger_speed ( speed ) ;
trigger_direction ( direction ) ; show_direction ( direction ) ; _delay_ms ( 250 ) ;
}

return 0;
}

### 6.2.4. Init-Methode

Die Methode init initialisert die GPIOs (General Porpuse Input/Output) des ATTINY.

Listing 3: Setup-Method

// **************************************************************************** // initialize gpio , set pin directions
// ***************************************************************************/ void init ( void )
{
// leds
GPIO_init ( DDR_LED5 , PIN_LED5 , OUTPUT ) ; // 1 GPIO_init ( DDR_LED6 , PIN_LED6 , OUTPUT ) ; // 2 GPIO_init ( DDR_LED7 , PIN_LED7 , OUTPUT ) ; // 3 GPIO_init ( DDR_LED8 , PIN_LED8 , OUTPUT ) ; // 4

GPIO_init ( DDR_LED1 , PIN_LED1 , OUTPUT ) ; // red GPIO_init ( DDR_LED2 , PIN_LED2 , OUTPUT ) ; // blue GPIO_init ( DDR_LED3 , PIN_LED3 , OUTPUT ) ; // green GPIO_init ( DDR_LED4 , PIN_LED4 , OUTPUT ) ; // yellow

// motor control
GPIO_init ( DDR_DIRECTION_BACKWARD , PIN_DIRECTION_BACKWARD , OUTPUT ); // backward
GPIO_init ( DDR_DIRECTION_FORWARD , | PIN_DIRECTION_FORWARD , | OUTPUT ); //
forward
GPIO_init ( DDR_PWM , PIN_PWM , OUTPUT ) ; // PWM
PWM_enable ( MODE_PWM , CLOCK_PWM , REGISTER_PWM , PWM_OFF );

// button

22

GPIO_init ( DDR_BUTTON , PIN_BUTTON , INPUT ) ;
GPIO_interrupt ( PORT_BUTTON , PIN_BUTTON , INT0 , EDGE_TYPE_BUTTON );

// timer interrupt
TIMER_enable ( MODE_TIMERA , MODE_TIMERB ) ;

// Enable interrupts
sei () ;
}

### 6.2.5. Setup-Methode

Die Setup-Methode initialisert das loolou-Programm mit den default-Werten.

Listing 4: Init-Method

// **************************************************************************** // setup syStem with default values
// ***************************************************************************/ void init ( void )
{
// set initial values
active_led | = LED1 ;
mode | = M_NORMAL_FORWARD ;
speed | = PWM_3V ;
direction | = FORWARD ;

// show current mode
show_mode () ;

// set seed
init_random ( TCNT1L ) ;

// initial pwm
trigger_speed ( PWM_3V ) ;

// set initial timer delay TIMER_set ( TIMER_INT_DEPLAY ) ; }

### 6.2.6. Interrupt Service Routine

Das Programm loolou implementiert zwei verschiedene Interrupt Service Routinen (ISR) - die ISR(INT0 vect) und ISR(TIMER1 COMPA vect).
Die ISR(INT0 vect) wird bei einer fallenden Flanke am Drucktaster aufgerufen. In der ISR(INT0 vect)
wird der Modus des Spieles um eins hochgezählt und neu ausgegeben. Anschließend wird der Timer
zuruckgesetzt und aufgerufen um die neue Geschwindigkeit und Spiel ¨ | -Richtung zu setzen.
Die Interrupt Service Routine ISR(TIMER1 COMPA vect) wird jede Sekunde aufgerufen und berechnet die Geschwindigkeit und die Spiel-Richtung neu.

Listing 5: Interrupt Service Routine

// ****************************************************************************

23

// interrupt service routine
// ***************************************************************************/ ISR ( INT0_vect )
{
ADD_ONE_BETWEEN ( mode , M_NORMAL_FORWARD , M_RANDOM_RANDOM ); show_mode () ;

/* reset timer , call ISR to change speed / direction immediately */ TIMER_reset () ;
TIMER1_COMPA_vect () ;
}

ISR ( TIMER1_COMPA_vect )
{
direction = calc_direction () ; speed = calc_speed () ;
}

### 6.2.7. Calculate direction Methode

Die Funktion calc direction gibt anhand des aktuellen Spielmodus die Spiel-Richtung zuruck. F ¨ ur die ¨ drei Spielmodis “Einfacher Modus“, “Schneller Modus“ und “Zufälliger Modus“ wird immer die Spiel-
Richtung “forwärts“ ausgeben. Im Spielmodus “Zufälliger Modus mit Ruckw ¨ | ärtsgang“ wird anhand
einer Zufallszahl die Spiel-Richtung berechnet. In diesem Modus wird etwa 10% “ruckw ¨ | ärts“ und etwa
90% “forwärts“ zuruckgegeben. ¨

Listing 6: Calculate direction

// **************************************************************************** // calculates a new direction
// ***************************************************************************/ GameDirection calc_direction ( void )
{
switch ( mode )
{
case M_NORMAL_FORWARD :
case M_FAST_FORWARD :
case M_RANDOM_FORWARD :
default :
return FORWARD ;
break ;
case M_RANDOM_RANDOM :
return ( ( get_random_between ( 0 , 10 ) == 0) ? BACKWARD : FORWARD ) ; /* 10% backward : 90% forward */
break ;
}
}

### 6.2.8. Calculate speed Methode

Die Funktion calculate speed gitb anhand des Spielmodus die berechnete Geschwindigkeit zuruck. Im ¨ Modus “Einfacher Modus“ wird immer der PWM-Wert fur 3V und im Modus “Schneller Modus“ ¨
der PWM-Wert fur 9V zur ¨ | uckgeliefert. In den Spielmodis “Zuf ¨ | älliger Modus“ und “Zufälliger Modus
mit Ruckw ¨ | ärtsgang“ wird die Geschwindigkeit anhand zweier Zufallszahlen berechnet. Dabei wird die

24

erste Zufallszahl fur die grobe Einordnung der Geschwindigkeit verwendet und die zw ¨ | eite Zufallszahl
fur die exakten PWM-Wert, der dann auch zur ¨ | uckgegeben wird. Die erste Zufallszahl ist in dieser ¨
BErechnung notwendig um größere Sprunge zwischen den Geschwindigkeiten zu reduzieren. Die Werte ¨ sind wie folgt aufgeteilt: Etwa 10% zwischen 0.0V und ˜3.5V, etwa 70% zwischen ˜3.5V und ˜7.0V, sowie 20% zwischen ˜7.0V und ˜9.0V.

Listing 7: Calculate Speed

// **************************************************************************** // calculates a new speed
// ***************************************************************************/ uint8_t calc_speed ( void )
{
switch ( mode )
{
case M_NORMAL_FORWARD :
default :
return PWM_3V ;
break ;
case M_FAST_FORWARD :
return PWM_9V ;
break ;
case M_RANDOM_FORWARD :
case M_RANDOM_RANDOM :
{
/*
* Calculate speed in 25 steps .
* 0 = 0V , ... , 25 = ~9 V
*
* For a better and faster playing pleasure ,
* a probability of
* 10% values between 0 V and 3 ,5 V and
* 70% values between 3 ,5 V and 6 ,0 V is selected . * 20% values between 7 ,0 V and 9 ,0 V is selected . */
static uint8_t r = 0;
r = get_random_between ( 0 , 10 ) ;
if ( r == 0 )
{ /* 20% slow ( 0 V - ~3 ,5 V ) */ return get_random_between ( 0 , 100 ) ; }
else if ( r == 1 || r == 2 )
{ /* 20% very fast /~7 ,0 V - 9 ,0 V */ return get_random_between ( 201 , 255) ; }
else
{ /* 70% fast ( ~3 ,5 V - ~7 ,0 V ) */ return get_random_between ( 101 , 200 ); }
}
break ;

}
}

25

### 6.3. Kompilieren des Sourcecodes

### 6.3.1. Abhängigkeiten an das Buildsystem

Um den C-Sourcecode fur den ATTINY2313 zu ¨ | ubersetzen werden einige wenige Anfoderungen an das ¨
Buildsystem gestellt. Es wir lediglich die AVR-Toolchain (avr-gcc) und ein Programmer fur Atmel- ¨ Mikrocontroller benötigt (avrdude). Um die Dokumentation zu erstellen wird zusätzlich ein LaTeX-Kompiler benötigt, unter Ubuntu oder Debian bietet sich hier zum Beispiel texlive an.
Fur Ubuntu und Debian k ¨ | önnen die folgenden Befehle, zum installieren der Abhängigkeiten, ver-
wendet werden.
| Listing 8: Build dependencies

# install avr toolchain and avr programmer sudo apt - get install gcc - avr avrdude

# install LaTeX - Compiler

sudo apt - get install texlive - full

### 6.3.2. Kompilieren

Das Kompilieren des C-Sourcecodes durch einen einfachen Make-Aufruf angestoßen werden. Dazu muss im Root-Verzeichniss des Sourcecodes folgender Befehl eingegeben werden.

Listing 9: Compile

# compile loolou

make

### 6.3.3. Aufräumen

Um die Kompilierten Source wieder zu löschen kann der folgende Befehl verwendet werden.

Listing 10: Clean

# clean loolou sources

make clean

### 6.3.4. Erstellen der Dokumentation

Das erstellen der Dokumentation kann ebenso wie das kompilieren des Sourcecodes durch einen Make-
Aufruf ausgefuhrt werden. Dazu f ¨ | ugt man das Schl ¨ | usselwort “doc“ dem “make“ an. ¨

Listing 11: Create documentation

# create documenation

make doc

26

# clean documenation

make doc - clean

### 6.4. Wie der Attiny2313 programmiert wird

### 6.4.1. Programming

Ebenso wie das Kompilieren der Source kann der Attiny mittels eines vordefinierten Make-Aufrufs pro-
grammiert werden. Dies kann uber den Befehl “make burn“ ausgef ¨ | uhrt werden. Mittels den Variablen ¨
AVRDUDE PROGRAMMER und AVRDUDE PORT kann das Device und der Programmer-Typ definiert werden. Die Default-Einstellungen sind avrispv2 fur den Typ des Programmers und ¨
/dev/ttyAMC0 fur das Device. Der Typ des Programmers kann der Dokumentation des Program ¨ | -
mers entnommen werden.

Achtung: Sollte der Programmer eine eigene Stromversorgung fur den Attiny haben, ¨ dann darf der 9V Stromanschluss des Looping Louie nicht angeschlossen werden, wenn
das Programmieren uber die eingebaute Programmier-Schnittstelle (J1) stattfindet. An ¨ | dernfalls kann
der Programmer beschädigt werden.

Listing 12: Programming

# flash the attiny ( using default values )

make burn
# or

make AVRDUDE_PROGRAMMER = avrispv2 AVRDUDE_PORT =/ dev / ttyAMC0 burn # AVRDUDE_PROGRAMMER define programmer type
# AVRDUDE_PORT define programmer device

27

### 7. Komponenten

In der folgenden Tabelle (Tabelle 4) sind alle benötigten Komponenten fur die Looping Louie Er- ¨ weiterung aufgelistet. Diese können uber https://www.reichelt.com bezogen werden. Die Platine muss ¨
seperat uber https://aisler.net/ bestellt werden. Der Bestelllink f ¨ | ur die Platine steht im Kapitel 7.1 ¨
auf Seite 28.
Reference | Description | - | -
U1 | IC-Sockel, 20polig | GS 20 | 0,25 e
U2 | IC-Sockel, 16polig | GS 16 | 0,18 e
U3 | Festspannungsregler | LF50CV | 0,18 e
J1 | Wannenstecker, 10polig, gerade | WSL 10G | 0,09 e
J2 | Hohlstecker-Buchse ∅2.1mm | HEBL 21 | 0,27 e
J3 | Motor-Anschluss | | -
SW1 | Drucktaster | | 1,04 e
C1 | Keramik-Kondensator, 0.1µF | | 0,26 e
C2 | Elekrolyt-Kondensator, 0.1µF | | 0,06 e
C3 | Elekrolyt-Kondensator, 2.2µF | | 0,17 e
D1 | LED, 5mm, rot | | 0,36 e
D2 | LED, 5mm, gruen | | 0,53 e
D3 | LED, 5mm, blau | | 0,53 e
D4 | LED, 5mm, gelb | | 0,41 e
D5 | LED, 3mm, rot | | 0,21 e
D6 | LED, 3mm, rot | | 0,21 e
D7 | LED, 3mm, rot | | 0,21 e
D8 | LED, 3mm, rot | | 0,21 e
R1 | Widerstand, 68Ω | | 0,09 e
R2 | Widerstand, 68Ω | | 0,09 e
R3 | Widerstand, 68Ω | | 0,09 e
R4 | Widerstand, 68Ω | | 0,09 e
R5 | Widerstand, 120Ω | | 0,09 e
R6 | Widerstand, 120Ω | | 0,09 e
R7 | Widerstand, 120Ω | | 0,09 e
R8 | Widerstand, 120Ω | | 0,09 e
- | Microcontroller ATTINY2313-20PU | ATTINY 2313V20PU | 3,45 e
- Kupferlitze isoliert, 90cm, 1x0,14mm, rot
- Kupferlitze isoliert, 90cm, 1x0,14mm, schwarz
- | Steckernetzteil, 9V | HNP 06-090L6 | 7,20 e
- loolou-Platine

Tabelle 4: Components

### 7.1. Platine

Das Platinen-Layout wurde mittels des Open-Souorce Tools kicad (http://kicad-pcb.org/) erstellt. Beziehen kann man die
Platine einfach und dazu noch gunstig ¨ | uber Aisler - eine niederl ¨ | ändische Firma die unteranderem ihre
Platinen in Deutschland herstellen lässt. Allerdings lassen sich hier die Platinen nur als ein vielfaches

28 von drei bestellen. Was aber in den meisten Fällen trotzdem noch gunstiger ist als vergleichbare Un- ¨ ternehmen.

Die Platine ist bereits bei Aisler hinterlegt und kann uber den folgenden Link bestellt werden. ¨

https://aisler.net/berauser/loolou/main-pcb

29

### 8. Lizenz

loolou ist lizenziert unter der Charityware. Sie können es verwenden und kopieren, so viel Sie
wollen, aber ich möchte Sie ermutigt, fur ein Kinder-Wohlt ¨ | ätigkeitsprojekt Ihrer Wahl zu spenden.

loolou is Charityware. You can use and copy it as much as you like, but you are encouraged to make a donation to a childrens’s charity project of your choice.

### 9. Haftungsausschluss

Ich ubernehme keinerlei Haftung f ¨ | ur jeglichen Schaden (Schaden an Gegenst ¨ | änden, Personen oder
jeglichen anderen Schaden), welcher in Zusammenhang mit der der Benutzung und den Umbau durch die von mir bereitgestellte Looping Louie-Erweiterung “loolou“ entsteht.
Ich ubernehme keinerlei Gew ¨ | ähr fur die Aktualit ¨ | ät, Korrektheit, Vollständigkeit oder Qualität der
bereitgestellten Informationen. Haftungsanspruche gegen mich, die sich auf Sch ¨ | äden materieller oder
ideeller Art beziehen, welche durch die Nutzung oder Nichtnutzung der dargebotenen Informationen, Programmen etc. bzw. durch die Nutzung fehlerhafter und unvollständiger Informationen verursacht wurden sind grundsätzlich ausgeschlossen, sofern kein nachweislich vorsätzliches oder grob fahrlässiges Verschulden durch mich vorliegt.

30

### Abbildungsverzeichnis

1. | Looping Louie mit loolou Erweiterung | | 1
2. | Spielbasis - Unterseite aufschrauben | | 6
3. | Spielbasis - geöffnet | | 6
4. | Spielbasis - geöffnet | | 7
5. | Spielbasis - Abdeckung | | 7
6. | Spielbasis - Unterseite Abdeckung ohne Motor und Batteriekontakten | | 8
7. | Spielbasis - Unterseite beim Aussägen | | 8
8. | Spielbasis - Unterseite ausgesägt und geschliffen | | 9
9. | Spielbasis - Oberseite mit Gewinde das entfernt werden muss | | 9
10. Schablonen und Oberteil der Spielbasis | | 10
11. Spielbasis - Gebohrte Löcher fur die LEDs und den Taster im Oberteil | | 10 ¨
12. Spielbasis - Mit gebohrten Löchern in der Seite des Oberteils | | 11
13. Spielbasis - Mit gesteckten LEDs, dem Drucktaster und dem Stromanschluss | | 11
14. Originale Platine - Revision 1 | | 13
15. Platine mit aufgelöteten Widerständen und IC-Sockel | | 13
16. Platine festgeschraubt im Oberteil der Spielbasis | | 14
17. Platine mit LEDs auf der Unterseite | | 14
18. Pin-Layout Hohlstecker-Buchse “HEBL 21“ | | 15
19. Platine mit allen Bauteilen (ohne Motor) | | 16
20. Spielbasis mit eingesetzter Platine | | 17
21. Zusammengebaute Spielbasis ohne Batteriefachabdeckung | | 17
22. Platine mit allen Bauteilen | | 18

### Tabellenverzeichnis

1. | Werkzeuge | | 4
2. | Litzenlänge | | 15
3. | Spielmodi | | 19
4. | Components | | 28

### Listings

1. | Defines | | 20
2. | Main-Method | | 22
3. | Setup-Method | | 22
4. | Init-Method | | 23
5. | Interrupt Service Routine | | 23
6. | Calculate direction | | 24
7. | Calculate Speed | | 25
8. | Build dependencies | | 26
9. | Compile | | 26
10. Clean | | 26
11. Create documentation | | 26
12. Programming | | 27

31

### 10. Anhang

32

A. Layout

B. Schaltplan

### C. Template

35

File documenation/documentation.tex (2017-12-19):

\documentclass[a4paper]{scrartcl}

%%%%%%%%%%%%%%%%%%%%%%%%%%%%%%%%%%%%%%%%%%%%%%%%%%%%%%%%%%%
%
% Includes and setup
%
%%%%%%%%%%%%%%%%%%%%%%%%%%%%%%%%%%%%%%%%%%%%%%%%%%%%%%%%%%%
\usepackage{geometry}
 \geometry{
  left=20mm,
  right=20mm,
  top=20mm,
 }
\usepackage{ngerman}   % german linguistics
\usepackage{textcomp}  % textmu, textohm
\usepackage{amssymb}   % varnothing
\usepackage{eurosym}   % \EUR{}
\usepackage{graphicx}  % includegraphicx
\usepackage{subfigure} % subfigure
\usepackage{hyperref}  % href
\usepackage{pdfpages}  % includepdf
\usepackage{listings}  % lstlisting
 %\lstset{
 % language=C
 %}
 \lstdefinestyle{customc}{
   basicstyle=\ttfamily\scriptsize,
   belowcaptionskip=1\baselineskip,
   breaklines=true,
   frame=L,
   xleftmargin=\parindent,
   language=C,
   showstringspaces=false,
   basicstyle=\footnotesize\ttfamily,
   keywordstyle=\bfseries\color{green!50!black},
   commentstyle=\itshape\color{blue},
   identifierstyle=\color{black},
   stringstyle=\color{orange},
 }
 \lstset{escapechar=@,style=customc}

%%%%%%%%%%%%%%%%%%%%%%%%%%%%%%%%%%%%%%%%%%%%%%%%%%%%%%%%%%%
%
% Documentation
%
%%%%%%%%%%%%%%%%%%%%%%%%%%%%%%%%%%%%%%%%%%%%%%%%%%%%%%%%%%%
\begin{document}

	%%%%%%%%%%%%%%%%%%%%%%%%%%%%%%%%%%%%%%%%%%%%%%%%%%%
	% Author
	%%%%%%%%%%%%%%%%%%%%%%%%%%%%%%%%%%%%%%%%%%%%%%%%%%%
	\author{Benjamin Rauser}
	\title{loolou}
	\subtitle{Looping Louie Erweiterung}
	%%%%%%%%%%%%%%%%%%%%%%%%%%%%%%%%%%%%%%%%%%%%%%%%%%%

	% title page --------------------------------------
	\input{title}
	\newpage

	% tabel of contents -------------------------------
	\tableofcontents
	\newpage

	% motivation --------------------------------------
	\section{Motivation}
	\input{motivation}
	\newpage

	% tools -------------------------------------------
	\section{Werkzeug}
	\input{tools}
	%\newpage

	% hints -------------------------------------------
	\section{Hinweise}
	\input{hints}
	\newpage

	% changelog ---------------------------------------
	\section{Changelog}
	\input{changelog}
	\newpage

	% instructions ------------------------------------
	\section{Anleitung}
	\input{instructions}
	\newpage

	% instructions ------------------------------------
	\section{Programm}
	\input{program}
	\newpage

	% components --------------------------------------
	\section{Komponenten}
	\input{components}
	\newpage

	% licence / dislaimer -----------------------------
	\section{Lizenz}
	\input{licence}
	\vspace{0.5cm}
	\section{Haftungsausschluss}	
	\input{disclaimer}
	\newpage

	% list if figures ---------------------------------
	\listoffigures
	%\newpage

	% list of tables ----------------------------------
	\listoftables
	%\newpage

	% table of listings -------------------------------
	\lstlistoflistings
	\newpage

	% Appendix ----------------------------------------
	\section{Anhang}
	\input{appendix}

\end{document}

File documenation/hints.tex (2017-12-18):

\subsection{Revision 1}
\begin{itemize}
\item Das Loch f"ur den Drucktaster und der Befestigungsschraube sind zu klein. Diese sollte vorsichtig aufgebohrt werden. 
\end{itemize}

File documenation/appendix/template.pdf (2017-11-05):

on/off

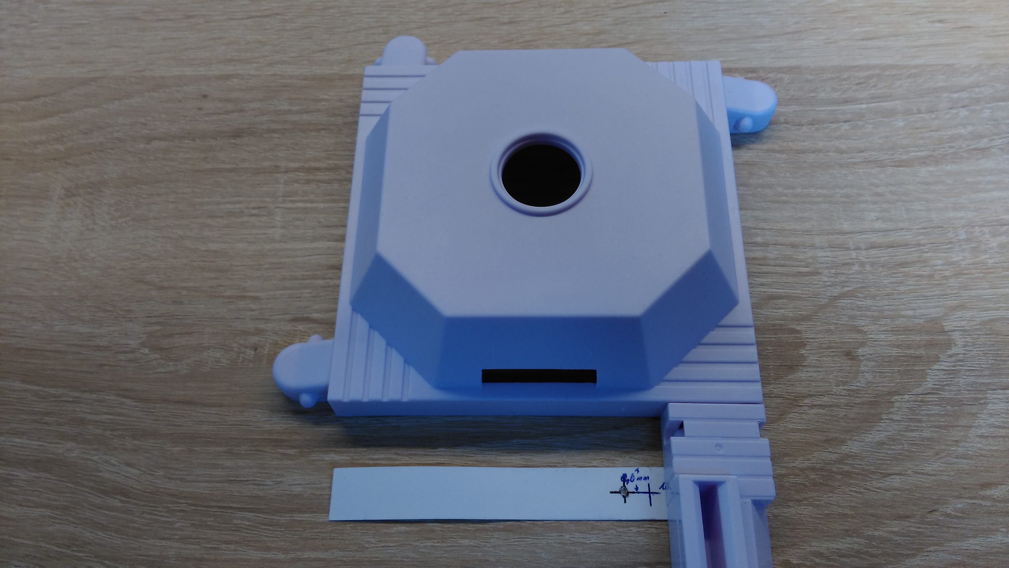
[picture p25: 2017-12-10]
documenation/pictures/loolou_011.jpg

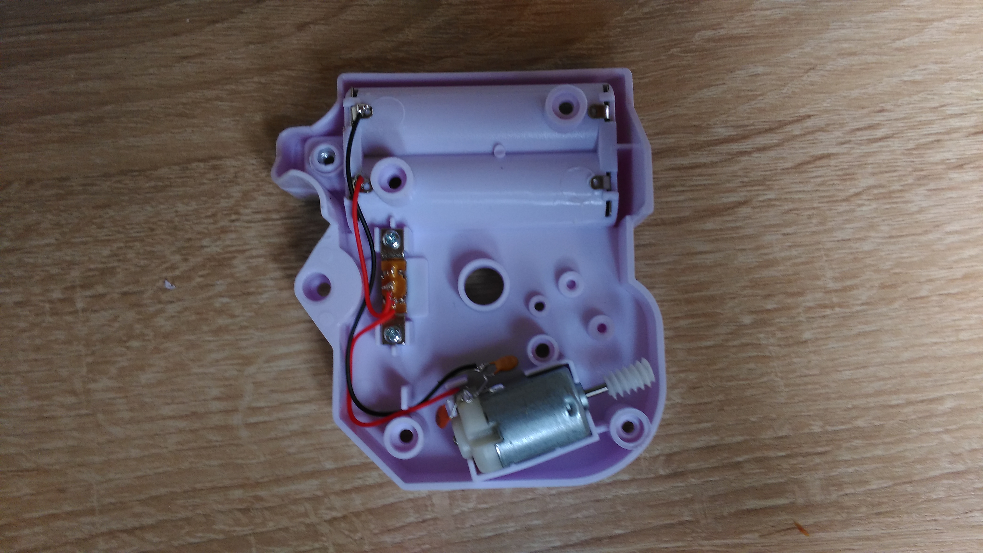
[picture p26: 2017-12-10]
documenation/pictures/loolou_006.jpg

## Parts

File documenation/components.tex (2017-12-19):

% components.tex
In der folgenden Tabelle (Tabelle ~\ref{table:components}) sind alle ben"otigten Komponenten f"ur die Looping Louie Erweiterung aufgelistet. Diese k"onnen "uber \href{https://www.reichelt.com}{https://www.reichelt.com} bezogen werden.
Die Platine muss seperat "uber \href{https://aisler.net}{https://aisler.net/} bestellt werden. Der Bestelllink f"ur die Platine steht im Kapitel ~\ref{subsection:pcb} auf Seite ~\pageref{subsection:pcb}.

\begin{center} % center the table
	\begin{table}[ht]
	\centering

		\begin{tabular}{ | l | l | l | l | l | } 

			\hline % table header
			Reference & Description					& - 			& - 		& \\ 
			\hline \hline
			% ------------------------------------------------------------------------------------------
			U1 	& IC-Sockel, 20polig				& GS 20			& \EUR{0,25} 	& \\ 
			\hline
			U2 	& IC-Sockel, 16polig				& GS 16 		& \EUR{0,18} 	& \\ 
			\hline
			U3 	& Festspannungsregler				& LF50CV		& \EUR{0,18} 	& \\ 
			\hline
			J1 	& Wannenstecker, 10polig, gerade		& WSL 10G		& \EUR{0,09} 	& \\ 
			\hline
			J2 	& Hohlstecker-Buchse $\varnothing 2.1mm$	& HEBL 21		& \EUR{0,27} 	& \\ 
			\hline
			J3 	& Motor-Anschluss				& 			& -		& \\ 
			\hline
			SW1 	& Drucktaster					& 			& \EUR{1,04} 	& \\ 
			\hline
			C1 	& Keramik-Kondensator, 0.1\textmu F		& 			& \EUR{0,26} 	& \\ 
			\hline
			C2 	& Elekrolyt-Kondensator, 0.1\textmu F		& 			& \EUR{0,06}	& \\ 
			\hline
			C3 	& Elekrolyt-Kondensator, 2.2\textmu F		& 			& \EUR{0,17}	& \\ 
			\hline
			D1 	& LED, 5mm, rot					& 			& \EUR{0,36}	& \\ 
			\hline
			D2 	& LED, 5mm, gruen				& 			& \EUR{0,53}	& \\ 
			\hline
			D3 	& LED, 5mm, blau				& 			& \EUR{0,53}	& \\ 
			\hline
			D4 	& LED, 5mm, gelb				& 			& \EUR{0,41}	& \\ 
			\hline
			D5 	& LED, 3mm, rot					& 			& \EUR{0,21}	& \\ 
			\hline
			D6 	& LED, 3mm, rot					& 			& \EUR{0,21}	& \\ 
			\hline
			D7 	& LED, 3mm, rot					& 			& \EUR{0,21}	& \\ 
			\hline
			D8 	& LED, 3mm, rot					& 			& \EUR{0,21}	& \\ 
			\hline
			R1 	& Widerstand, 68\textohm			& 			& \EUR{0,09} 	& \\ 
			\hline
			R2 	& Widerstand, 68\textohm			& 			& \EUR{0,09}	& \\ 
			\hline
			R3 	& Widerstand, 68\textohm			& 			& \EUR{0,09}	& \\ 
			\hline
			R4 	& Widerstand, 68\textohm			& 			& \EUR{0,09}	& \\ 
			\hline
			R5 	& Widerstand, 120\textohm			& 			& \EUR{0,09}	& \\ 
			\hline
			R6 	& Widerstand, 120\textohm			& 			& \EUR{0,09}	& \\ 
			\hline
			R7 	& Widerstand, 120\textohm			& 			& \EUR{0,09}	& \\ 
			\hline
			R8 	& Widerstand, 120\textohm			& 			& \EUR{0,09}	& \\ 
			\hline \hline
			% ------------------------------------------------------------------------------------------
			-	& Microcontroller ATTINY2313-20PU		& ATTINY 2313V20PU	& \EUR{3,45}	& \\
			\hline
			-	& Kupferlitze isoliert, 90cm, 1x0,14mm, rot	&			&		& \\
			\hline
			-	& Kupferlitze isoliert, 90cm, 1x0,14mm, schwarz	&			&		& \\
			\hline
			-	& Steckernetzteil, 9V				& HNP 06-090L6		& \EUR{7,20}	& \\
			\hline
			-	& loolou-Platine				&			&		& \\
			\hline
		\end{tabular}

	\caption{Components}
	\label{table:components}
	\end{table}
\end{center}

\subsection{Platine}\label{subsection:pcb}

Das Platinen-Layout wurde mittels des Open-Souorce Tools \href{http://kicad-pcb.org/}{kicad} erstellt. 
Beziehen kann man die Platine einfach und dazu noch g"unstig "uber Aisler - eine niederl"andische Firma die unteranderem ihre Platinen in Deutschland herstellen l"asst. Allerdings lassen sich hier die Platinen nur als ein vielfaches von drei bestellen. Was aber in den meisten F"allen trotzdem noch g"unstiger ist als vergleichbare Unternehmen. \\
\\
Die Platine ist bereits bei Aisler hinterlegt und kann "uber den folgenden Link bestellt werden. \\ \\
\begin{center}
\href{https://aisler.net/berauser/loolou/main-pcb}{https://aisler.net/berauser/loolou/main-pcb}
\end{center}

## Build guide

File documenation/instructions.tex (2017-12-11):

\subsection{Spielbasis}

\textbf{Zeitaufwand: 8h} \\

%\begin{figure}[h]
%	\centering
%  	\includegraphics[width=0.7\textwidth]{pictures/loolou_001.jpg}
%	\caption{Spielbasis - Unterseite}
%	\label{fig1}
%\end{figure}

Als erstes widmen wir uns der Spielbasis, zu sehen in Abbildung ~\ref{fig2}. Sie muss im ersten Schritt zerlegt und angepasst werden, um Platz f"ur die Platine zu schaffen. \\
\\
Dazu entfernen wir als erstes die 7 Schrauben an der Unterseite. \\
Die ersten 5 Schrauben sind mit blo"sem Auge von aussen sichtbar. Die letzten zwei Schrauben sind nach dem "offnen des Batteriefaches zu sehen.  

\vspace{0.5cm}
\begin{figure}[!ht]
	\centering
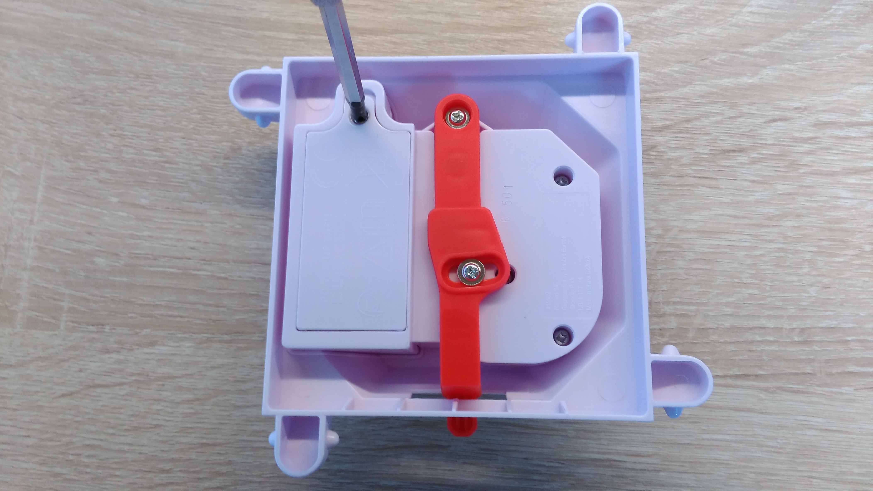
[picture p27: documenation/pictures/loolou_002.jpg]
  	
	\caption{Spielbasis - Unterseite aufschrauben}
	\label{fig2}
\end{figure}
\vspace{0.5cm}

Abbildung ~\ref{fig3} zeigt die Spielbasis nach dem entfernen der 7 Schrauben. 

\vspace{0.5cm}
\begin{figure}[!ht]
	\centering
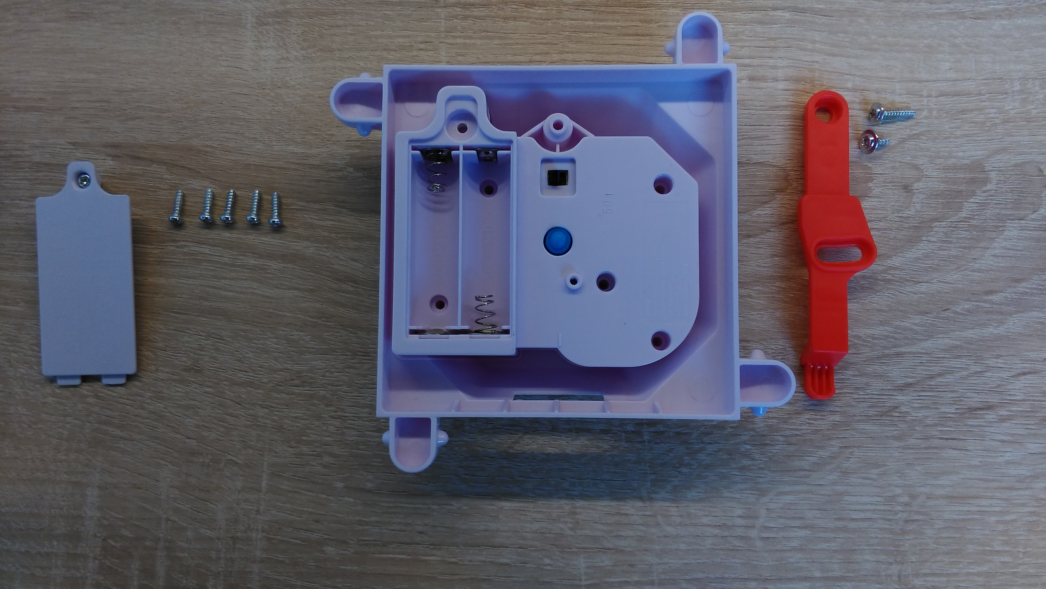
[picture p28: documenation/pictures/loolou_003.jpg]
  	
	\caption{Spielbasis - ge"offnet}
	\label{fig3}
\end{figure}
\vspace{0.5cm}

Anschlie"send muss die Spielbasis ge"offnet werden. Dazu zieht man das Innenteil der Spielbasis heraus.
Zu sehen ist nun das Getriebe, der Motor und der Stromschalter (siehe Abbildung ~\ref{fig4} und ~\ref{fig5}). 

\vspace{0.5cm}
\begin{figure}[!ht]
	\centering
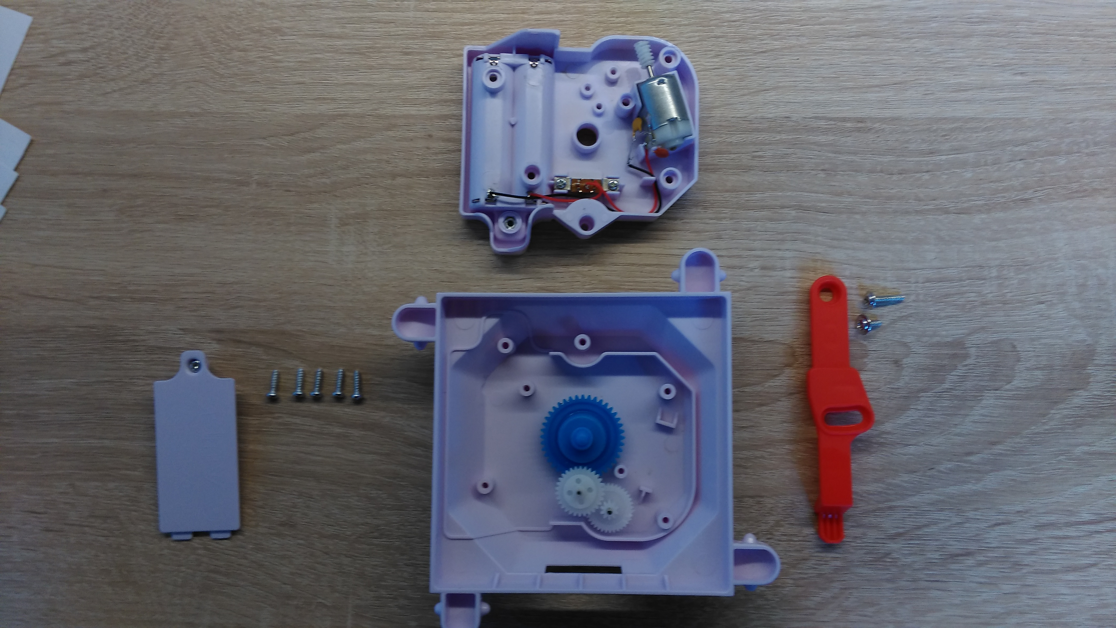
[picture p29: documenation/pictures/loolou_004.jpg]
  	
	\caption{Spielbasis - ge"offnet}
	\label{fig4}
\end{figure}
\vspace{0.5cm}
\begin{figure}[!ht]
	\centering
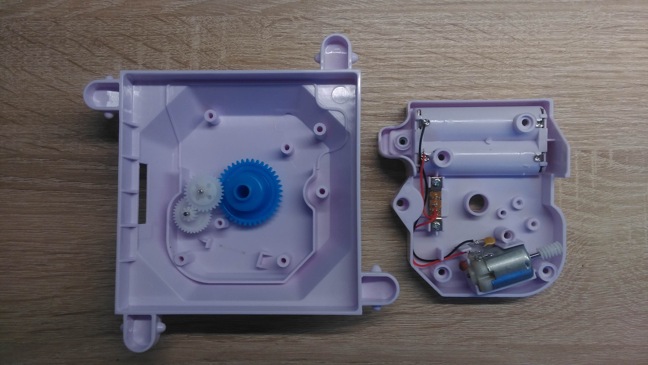
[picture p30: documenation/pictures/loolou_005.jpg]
  	
	\caption{Spielbasis - Abdeckung}
	\label{fig5}
\end{figure}
\vspace{0.5cm}

%\begin{figure}[!ht]
%	\centering
% 	\includegraphics[width=0.7\textwidth]{pictures/loolou_006.jpg}
%	\caption{um 30 Grad gedreht}
%	\label{fig6}
%\end{figure}

Nun muss der Motor, der Stromschalter und die Batteriekontakte entfernt werden. \\
Am besten l"ost man hierf"ur zuerst die Stromkabel, mit einem L"otkolben, von den Batteriekontakten. \\
Anschlie"send kann der Motor ganz einfach herausgezogen und der Stromschalter mittels eines Schraubenziehers entfernt werden.
Danach k"onnen die Batteriekontakte mit einer Zange herausgezogen werden.
Abbildung ~\ref{fig7} zeigt die Abdeckung der Spielbasis ohne Motor, Stromschalter und Batteriekontakte.

\vspace{1cm}
\begin{figure}[!ht]
	\centering
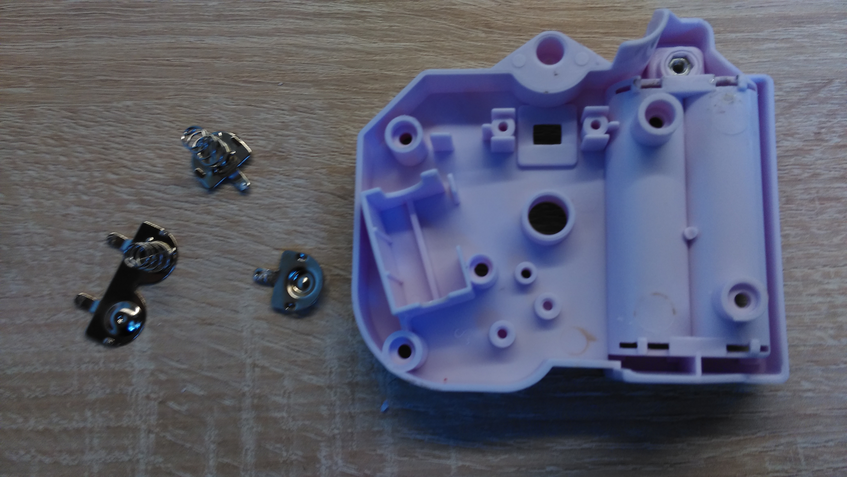
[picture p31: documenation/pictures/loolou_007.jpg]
  	
	\caption{Spielbasis - Unterseite Abdeckung ohne Motor und Batteriekontakten}
	\label{fig7}
\end{figure}
\vspace{0.5cm}

Als n"achstes muss Platz f"ur die Platine geschaffen werden. \\ 
Dazu bohrt man an den 4 Ecken des Batteriefaches jeweils ein Loch und s"agt mit einer S"age am Rand des Batteriefaches entlang (zu sehen in Abbildung ~\ref{fig8}). \\
Achte an dieser Stelle besonders auf das Geh"ause - Es sollte nicht brechen bzw. es sollte nicht weiter als die Umrandung des Batteriefach ges"agt werden. Ansonsten sieht man beim sp"ateren Zusammenbau der Spielbasis die Schnitte der S"age. Ebenso sollten keine Gewinde f"ur die Schrauben abges"agt werden, mit Ausnahme der Gewinde im Batteriefach. 
F"ur die feineren Arbeiten kann eine Feile benutzt werden. 
Anschließend muss in den herausstehenden Seiten jeweils eine Ecke herausgefeilt werden (Gut zu sehen in der Abbildung ~\ref{fig9}). Diese werden sp"ater ben"otigt um die Stromkabel f"ur die LEDs und des Netzteils aus der Spielbasis herauszuf"uhren.  

\vspace{1cm}
\begin{figure}[!ht]
	\centering
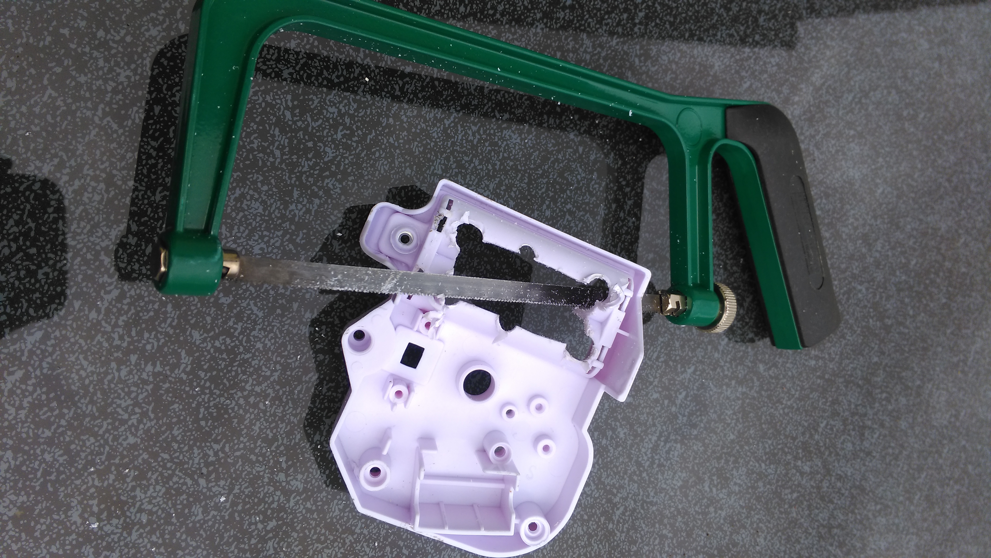
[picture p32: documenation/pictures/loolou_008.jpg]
  	
	\caption{Spielbasis - Unterseite beim Auss"agen}
	\label{fig8}
\end{figure}
\vspace{0.5cm}

Abbildung ~\ref{fig9} zeigt die fertig vorbereitete Unterseite der Spielbasis. Gut zu sehen sind hier die abgefeilten Ecken f"ur die Stromkabel und das ausges"agte Batteriefach.
Wichtig an dieser Stelle ist auch, dass das Batteriefach vollst"antig entfernt und bis auf den letzten Millimeter abgefeilt wurde. Ansonsten kann es vorkommen, dass das Geh"ause beim sp"ateren Zusammenbau nicht richtig schlie"st.

\vspace{1cm}
\begin{figure}[!ht]
	\centering
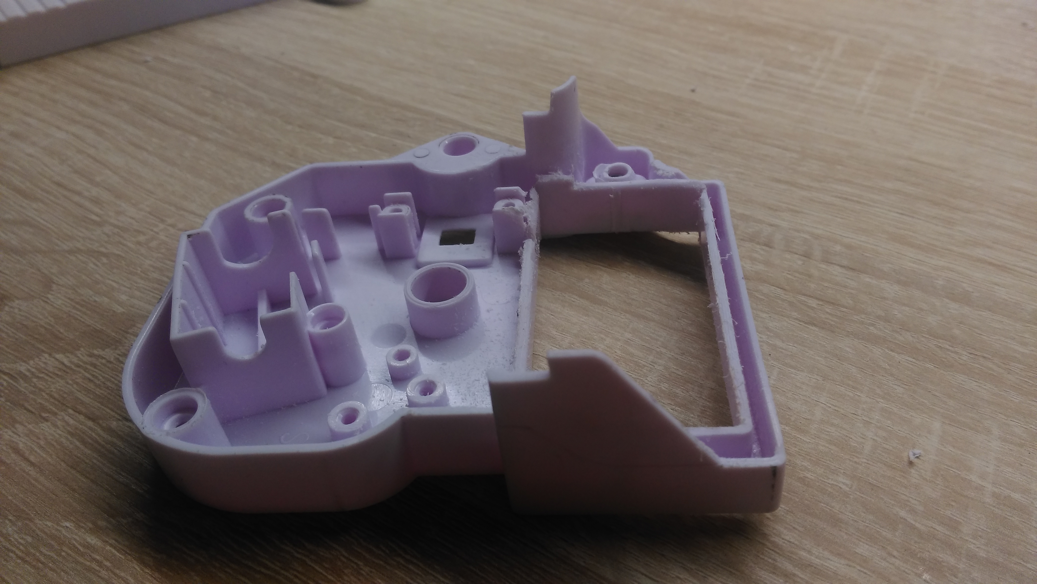
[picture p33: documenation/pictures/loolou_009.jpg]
  	
	\caption{Spielbasis - Unterseite ausges"agt und geschliffen}
	\label{fig9}
\end{figure}
\vspace{0.5cm}

Nun kann die Unterseite der Spielbasis zur Seite gelegt werden. Es folgt die Vorbereitung der Oberseite. \\
Als erstes sollte hier das Gewinde im linken oberen Eck (siehe Abbildung ~\ref{fig10}) mit einem Bohrer entfernt werden. Dieses Gewinde ist der Platine im Weg und muss daher entfernt werden.
Achte hierbei darauf das nicht durch das Oberteil gebohrt wird, lasse lieber ein bis zwei Millimeter "uberstehen.
 
\vspace{1cm}
\begin{figure}[!ht]
	\centering
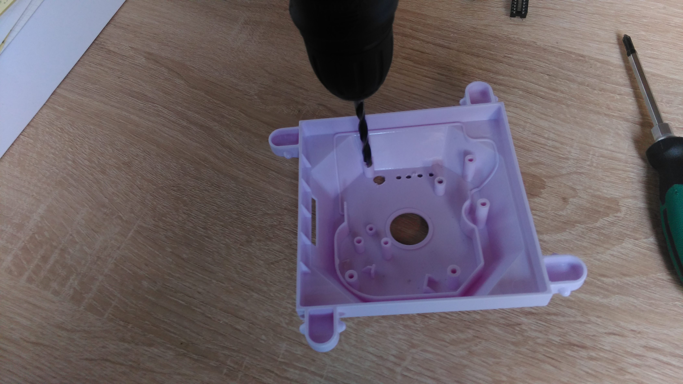
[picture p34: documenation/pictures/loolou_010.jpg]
  	
	\caption{Spielbasis - Oberseite mit Gewinde das entfernt werden muss}
	\label{fig10}
\end{figure}
\vspace{0.5cm}

%\begin{figure}[!ht]
%	\centering
% 	\includegraphics[width=0.7\textwidth]{pictures/loolou_011.jpg}
%	\caption{um 30 Grad gedreht}
%	\label{fig11}
%\end{figure}

Als n"achstes schneidet man zuerst die Schablonen (siehe Anhang ~\ref{appendix:template}) aus. Diese werden ben"otigt um die L"ocher f"ur die LEDs, den Taster und den Stromanschlu"s richtig zu positionieren.
Abbildung ~\ref{fig12} zeigt die Schablonen und das fertig Vorbereitete Geh"ause.

\vspace{1cm}
\begin{figure}[!ht]
	\centering
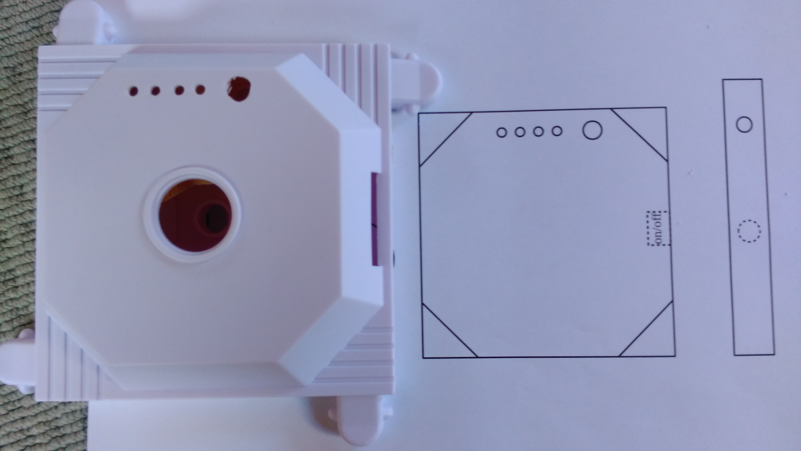
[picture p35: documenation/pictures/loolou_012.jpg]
  	
	\caption{Schablonen und Oberteil der Spielbasis}
	\label{fig12}
\end{figure}
\vspace{0.5cm}

Im n"achsten Schritt nimmt man den gro"se ausgeschnitten Teil der Schablone und legt ihn auf die Oberseite der Spielbasis. Man sollte hier darauf achten dass die Schrift \grqq{}on/off\grqq{} "uber dem AN/AUS-Schalter der Spielbasis liegt (zu sehen in Abbildung ~\ref{fig13}). Anschlie"send k"onnen zuerst mit einem spitzen Gegenstand (zum Beispiel einem Bohrer) die L"ocher auf dem Oberteil der Spielbasis angek"ornt werden.
Die kleinen L"ocher, f"ur die LEDs, werden nun mit einem 3mm-Bohrer durchbohrt. Im Anschluss wird das Loch f"ur den Drucktaster mit einem 7mm-Bohrer in das Oberteil gebohrt. 
Abbildung ~\ref{fig13} zeigt die gebohrten L"ocher in dem Oberteil der Spielbasis. Zu sehen ist hier auch dass die L"ocher auf der rechten Seite, vom AN/AUS-Schalter aus gesehen, liegen.  

\vspace{1cm}
\begin{figure}[!ht]
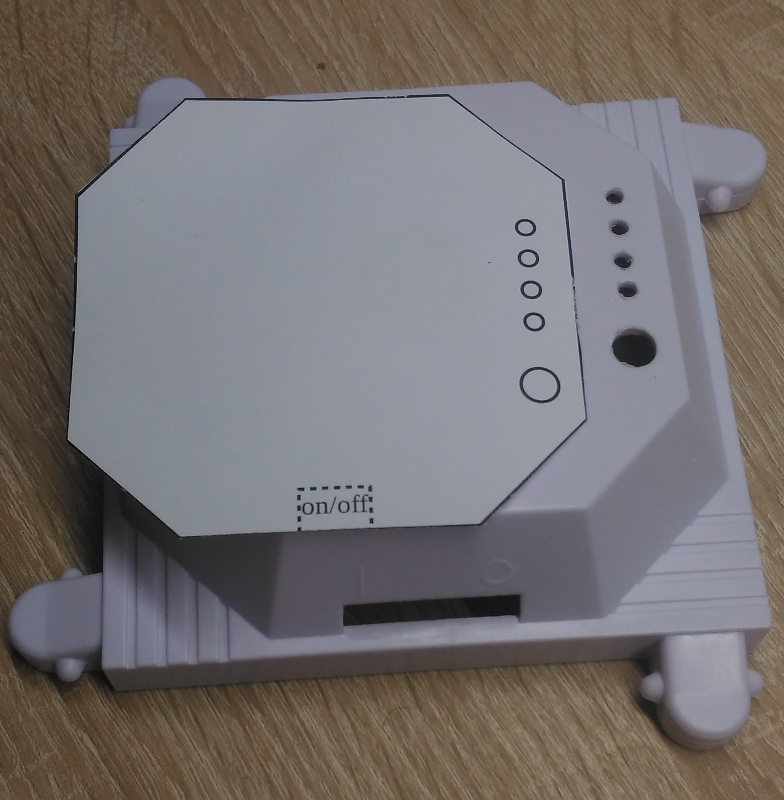
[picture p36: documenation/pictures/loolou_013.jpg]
  	
	\centering
	\caption{Spielbasis - Gebohrte L"ocher f"ur die LEDs und den Taster im Oberteil}
	\label{fig13}
\end{figure}
\vspace{0.5cm}
\newpage

Nun nimmt man das kleine rechteckige Teil der Schablone und k"ornt damit an jeder der 4 Seiten das Loch f"ur die 5mm gro"sen LEDs an (Kreis mit durchgezogener Linie). Dabei muss der Kreis mit der durchgezogenen Linie zu dem Verbindungsst"uck, f"ur die Arme des Looping Louie, zeigen (zu sehen in Abbildung ~\ref{fig14}). Der gestrichelte Kreis ist f"ur den Stromanschluss. Dieser wird auf der, dem des AN/AUS-Schalter gegeb"uberliegenden Seite, gebohrt (zu sehen in Abbildung ~\ref{fig14}). Die L"ocher f"ur die LEDs werden mit einem Bohrer der St"arke von 5mm und das Loch f"ur den Stromanschluss mit einen 7mm gro"sen Bohrer gebohrt.  

\vspace{1cm}
\begin{figure}[!ht]
	\centering
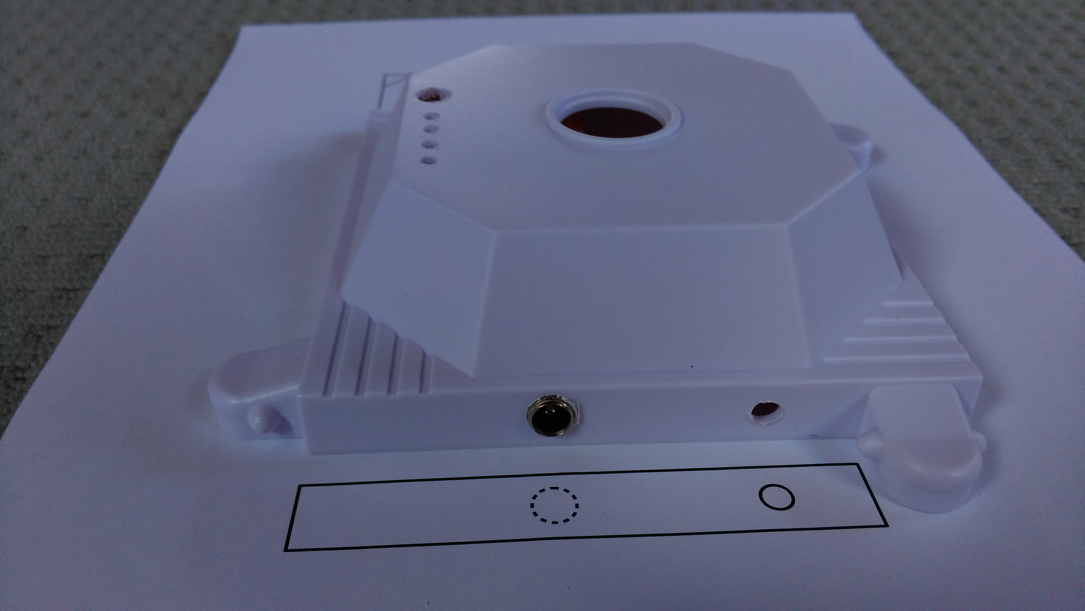
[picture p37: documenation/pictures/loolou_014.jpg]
  	
	\caption{Spielbasis - Mit gebohrten L"ochern in der Seite des Oberteils}
	\label{fig14}
\end{figure}
\vspace{0.5cm}

Zum Abschluss k"onnen nun noch alle LEDs, der Drucktaster und der Stromanschluss in die Spielbasis gesteckt werden. Sollte hier noch etwas klemmen kann an dieser Stelle noch leicht nachgearbeitet werden.

\vspace{1cm}
\begin{figure}[!ht]
	\centering
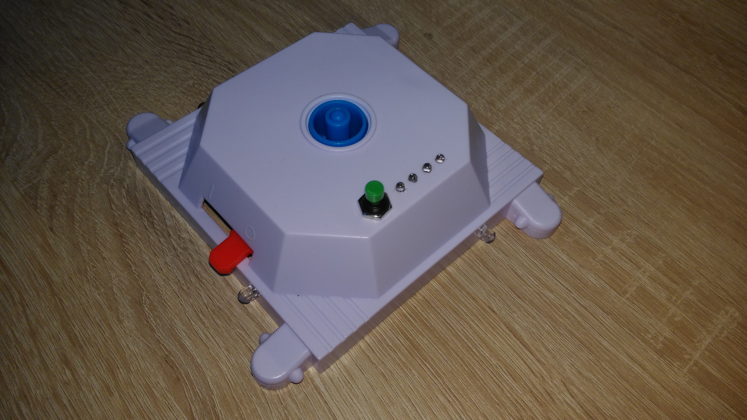
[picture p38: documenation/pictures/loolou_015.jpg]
  	
	\caption{Spielbasis - Mit gesteckten LEDs, dem Drucktaster und dem Stromanschluss}
	\label{fig15}
\end{figure}
\vspace{0.5cm}

Die Abbildung ~\ref{fig15} zeigt die Spielbasis mit den gesteckten LEDs, dem Drucktaster und dem Stromanschluss. 
Die Bauteile k"onnen nun wieder aus der Spielbasis entfernt und zur Seite gelegt werden.

\newpage
\subsection{Platine}

Nun widmen wir uns der Platine - dem Herzst"uck der Erweiterung von Looping Louie. Zu sehen ist diese in den Abbildungen ~\ref{fig16} (a) und (b).

\vspace{1cm}
\begin{figure}[!ht]
	\centering
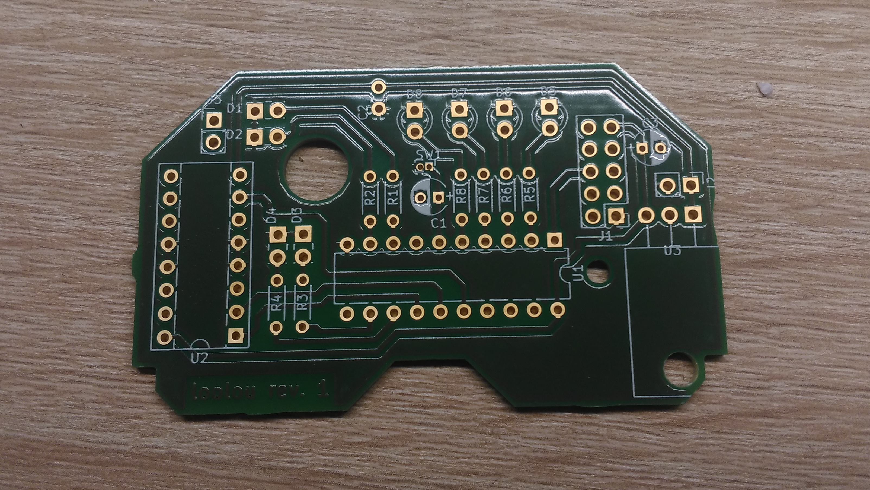
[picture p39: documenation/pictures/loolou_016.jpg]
  	\subfigure[Oberseite]{}
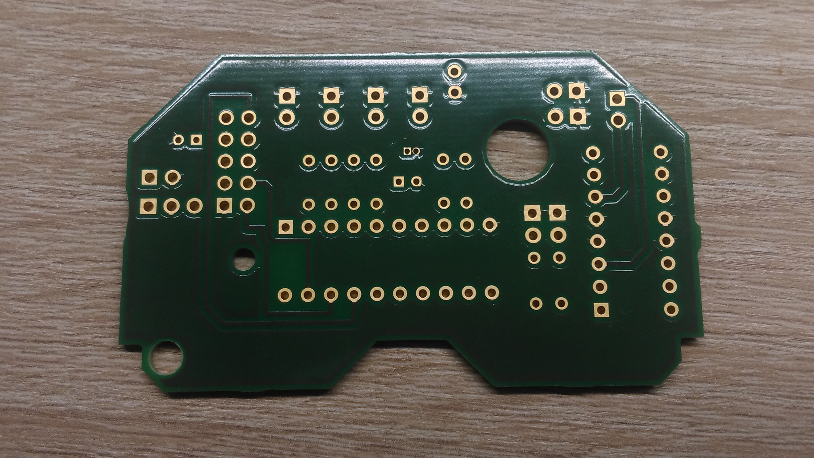
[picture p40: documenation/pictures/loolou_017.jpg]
	\subfigure[Unterseite]{}
	\caption{Originale Platine - Revision 1}
	\label{fig16}
	%\label{fig17}
\end{figure}
\vspace{0.5cm}

Auf der Platine sind unteranderem ein kleiner Microcontroller (ATTINY2313), ein Treiberbaustein, ein Festspannungsregler sowie diverse LEDs und Widerst"ande verbaut. Der Schaltplan ~\ref{appendix:shematics} und das Platinen-Layout ~\ref{appendix:layout} kann im Anhang gefunden werden. Die Referenzen der Bauteile k"onnen der Tabelle ~\ref{table:components} entnommen werden.  \\
\\
Am einfachsten beginnt man an dieser Stelle mit den IC-Sockeln (U1 und U2), sowie dem Festspannungsregler (U3). Im Anschluss kann der 10polige Wannenstecker (J1), f"ur den Programmer, aufgel"otet werden, dieser ist optional und wird nur ben"otigt wenn man den Attiny zum programmieren nicht herausnehmen m"ochte.
Nachdem die IC-Sockel und der Festspannungsregler aufgel"otet wurden, k"onnen die Widerst"ande (R1-R8) und die Kondensatoren (C1-C3) aufgel"otet werden.
Die Abbildung ~\ref{fig18} zeigt die Platinen nach dem aufl"oten der Widerst"ande, der Kondensatoren, dem Festspannungsregler und den IC-Sockeln.

\vspace{1cm}
\begin{figure}[!ht]
	\centering
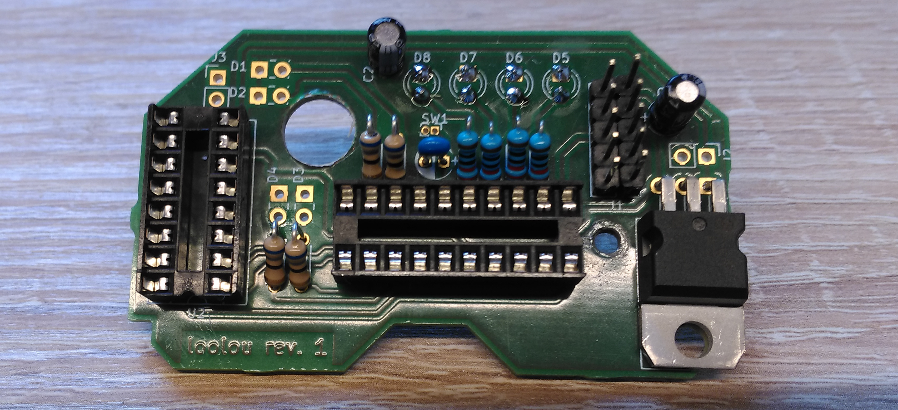
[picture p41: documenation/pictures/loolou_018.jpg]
  	
	\caption{Platine mit aufgel"oteten Widerst"anden und IC-Sockel}
	\label{fig18}
\end{figure}
\vspace{0.5cm}

Nachdem nun die IC-Sockel (U1,U2), der Festspannungsregler (U3), die Widerst"ande (R1-R8) und die Kondensatoren (C1-C3) aufgel"otet wurden, sollten die LEDs (D5-D8) aufgel"otet werden. Dazu steckt man diese einzeln, von innen, in das Oberteil der Spielbasis und schraubt dann die Platine in den daf"ur vorgesehenen Platz im Oberteil der Spielbasis. Wie die Platine in das Oberteil der Spielbasis geschraubt wird zeigt die Abbildung ~\ref{fig19} \\
Nachdem nun die LEDs in die Spielbasis gesteckt und die Dr"ahte der LEDs (D5-D8) durch die daf"ur vorgsehenen L"ocher gef"uhrt wurden, k"onnen diese an der Platine festgel"otet werden. Achte an dieser Stelle darauf das die LEDs richtig gepolt sind, ansonsten m"ussen diese sp"ater wieder entfernt und neu aufgel"otet werden.
% TODO Es ist einfacher wenn alle LEDs einzeln eingescteckt weren -> LED5 rein, festscahrauben, lötem, rasuschrauben -> nächste LED  

\vspace{1cm}
\begin{figure}[!ht]
	\centering
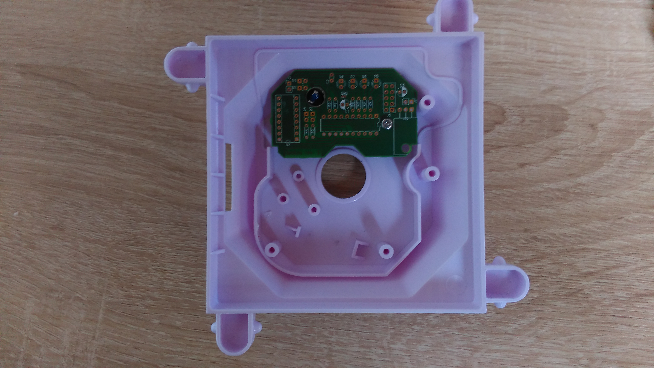
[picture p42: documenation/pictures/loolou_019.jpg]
  	
	\caption{Platine festgeschraubt im Oberteil der Spielbasis}
	\label{fig19}
\end{figure}
\vspace{0.5cm}

Nachdem nun auch die LEDs D5 bis D8 aufgel"otet sind kann die Platine nun wieder aus der Spielbasis herausgenommen werden. Die Abbildung ~\ref{fig20} zeigt die Platine mit den festgel"oteten LEDs (D5-D8). \\
Es empfiehlt sich an dieser Stelle die bisher festgel"oteten Bauteile und die L"otstellen mit einem Durchgangspr"ufer zu testen, um kalte L"otstellen und verpolte LEDs rechtzeitig zu erkennen.

\vspace{1cm}
\begin{figure}[!ht]
	\centering
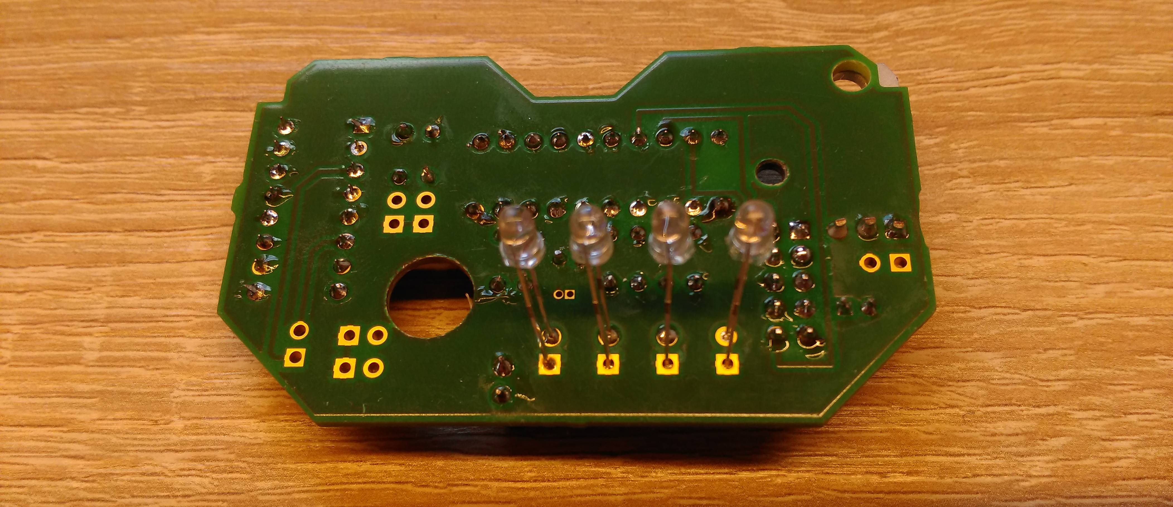
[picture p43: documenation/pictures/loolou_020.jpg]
  	
	\caption{Platine mit LEDs auf der Unterseite}
	\label{fig20}
\end{figure}
\vspace{0.5cm}

An dieser Stelle sollten die Litzen f"ur die restlichen LEDs (D1-D4), den Drucktaster (SW1), den Hohlstecker-Buchse (J2) und den Motor vorbereitet werden. Die L"ange der Litzen kann einfach der Tabelle ~\ref{table:cable} entnommen werden. Es werden jeweils eine rote und eine schwarze Litze ben"otigt.

\vspace{1cm}
\begin{table}[ht]
	\centering

	\begin{tabular}{ | l | l | l | } 
		\hline % table header
		Reference	& Description		& Length \\ 
		\hline \hline
		D1		& LED1, 5mm		& 9cm  \\
		\hline
		D2		& LED2, 5mm		& 13cm \\
		\hline
		D3		& LED3, 5mm		& 13cm \\
		\hline
		D4		& LED4, 5mm		& 13cm \\
		\hline
		SW1		& Drucktaster		& 5cm  \\
		\hline
		J1		& Hohlstecker-Buchse	& 7cm  \\
		\hline
		J3		& Motor			& 16cm \\
		\hline
	\end{tabular}

	\caption{Litzenl"ange}
	\label{table:cable}
\end{table}
\vspace{0.5cm}

Sobald diese vorbereitet wurden, k"onnen die Litzen bereits an die LEDs (D1-D4) gel"otet werden. Dazu schneidet man am Besten die Dr"ahte der LEDs auf einen Zentimeter herunter und l"otet dann die Kabel an. Im Anschluss sollten noch die offenen L"otstellen mit einem Schrumpfschlauch verschlossen werden. Anschlie"send k"onnen auch die Litzen an den Drucktaster und die Hochstecker-Buchse gel"otet und mit einem Schrumpfschlauch verschlossen werden. \\
Das Pin-Layout, der Hohlstecker-Buchse, kann dem Datenblatt entnommen werden. F"ur die Hohlstecker-Buchse \grqq HEBL 21\grqq  (\href{https://www.reichelt.com}{www.reichelt.com}) ist das Pin-Layout in der Abbildung ~\ref{fig21} zu sehen.

\vspace{1cm}
\begin{figure}[!ht]
	\centering
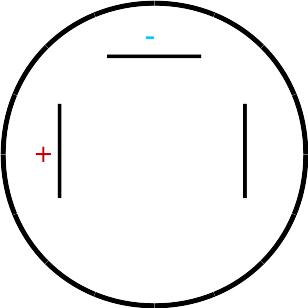
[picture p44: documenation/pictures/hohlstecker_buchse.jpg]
  	
	\caption{Pin-Layout Hohlstecker-Buchse \grqq HEBL 21\grqq }
	\label{fig21}
\end{figure}
\vspace{0.5cm} 

Die alten Litzen des Motors werden nun durch die neuen l"angeren Litzen ersetzt. Dabei muss die rote Litze einmal durchtrennt und wie gehabt mit dem Stromschalter verbunden werden. \\
\\
Im Anschluss wird der Drucktaster mit den angel"oteten Litzen, von unten in das gro"se Loch der Platine (zwischen R2 und D2) gesteckt. Die Litzen f"uhrt man dazu ebenfalls von unten nach oben durch das Loch.
Die beiden Litzen (rot und schwarz) werden nun an den beiden L"ochern von SW1 von oben festgel"otet. Die Polung spielt hier keine Rolle.\\
Sobald der Drucktaster SW1 an der Platine festgel"otet wurde, k"onnen die auch die LEDs (D1-D4), die Hohlstecker-Buchse (J2) und der Motor (J3) festgel"otet werden. Hierbei muss auf die Polung der LEDs, der Hohlstecker-Buchse und des Motors geachtetet werden - die schwarzen Litzen (Minus-Pol) m"ussen in die L"ocher mit den quadratischen Kontakten. Im Fall einer Verpolung kann es zu Sch"aden an der Platine, zu nicht funktionierenden LEDs oder einen Motor der in die falsche Richtung dreht kommen.
In der Abbildung ~\ref{fig22} ist die fertig gel"otete Platine zu erkennen (ohne Motor).

\vspace{1cm}
\begin{figure}[!ht]
	\centering
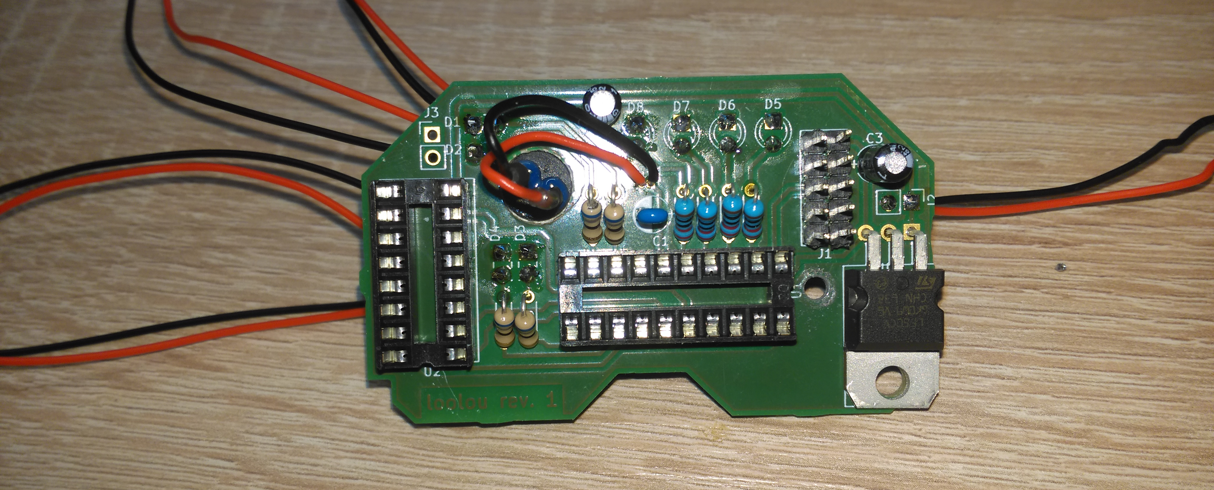
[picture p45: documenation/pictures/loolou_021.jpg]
  	\subfigure[Oberseite]{}
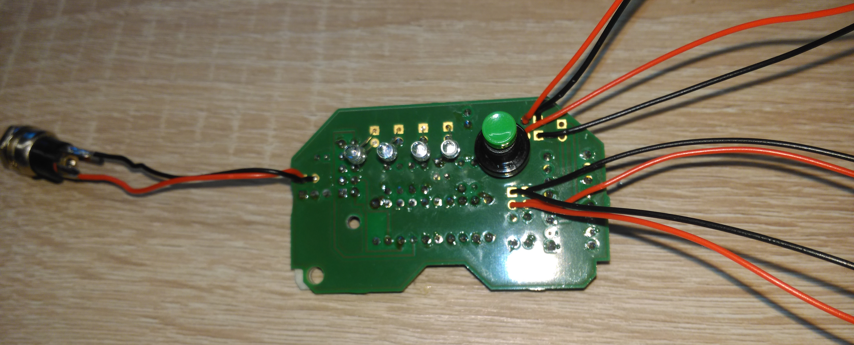
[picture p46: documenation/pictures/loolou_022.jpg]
	\subfigure[Unterseite]{}
	\caption{Platine mit allen Bauteilen (ohne Motor)}
	\label{fig22}
	%\label{fig23}
\end{figure}
\vspace{0.5cm}

Nun sollte die Platine nochmals mit dem Durchgangspr"ufer, auf kalte L"otstellen und verpolte Bauteile, "uberpr"uft werden. Ist hier kein Fehler zu finden, dann kann zum Testen das Netzteil angeschlossen werden. Wird der Festspannungsregler schnell sehr hei"s dann deutet dies auf einen Kurzschluss oder eine Verpolung hin. Weiterhin sollte zwischen den Pins 1 und 2 des Festspannungsregler eine Spannung von 9 Volt und zwischen Pin 2 und Pin 3 ein Spannung von 5V anliegen. \\

Im Anschluss kann der Attiny2313 und der Treiberbaustein (L293D) auf die Sockel gesteckt werden. Die hablrunden Einkerbungen m"ussen daf"ur "uber den wei"sen halbrunden Kreisen des Zeichnung (bei U1 und U2) liegen. \\

Steckt man nun wieder das Netzteil ein, dann sollten die LEDs D1 bis D5 abwechselnd und die LED D8 dauerhaft leuchten. Der Motor kann "uber den Stromschalter, zwischen J3 und Motor, an bzw. ausgeschaltet werden.
Durch den Druck auf den Drucktaster (SW1) k"onnen die LEDs D5 bis D7 getestet werden. \\
\\
Ist bisher kein Fehler erkennbar, dann kann man die Platine ausschalten und zur Seite legen.

\newpage
\subsection{Zusammenbau}

Nun werden alle Komponenten wieder zusammengebaut.
Beginnen muss man beim Zusammenbau mit dem Getriebe. Dazu nimmt man das blaue Zahnrad und steckt es in das gro"se Loch des Oberteils der Spielbasis. Anschlie"send m"ussen die wei"sen Zahnr"ader eingesetzt werden. Nachdem diese eingsetzt wurden, wird die Platine in das Oberteil geschraubt, dazu f"uhrt man die Litzen der LEDs, des Motors und der Hohlstecker-Buchse an der linken bzw. rechten Seite heraus. Der Stromschalter des Motors und der Motor selbst werden wieder in die Unterseite der Spielbasis eingesetzt bzw. festgeschraubt. Wie dies am Ende aussehen muss zeigt die Abbildung ~\ref{fig23}.

\vspace{0.5cm}
\begin{figure}[!ht]
	\centering
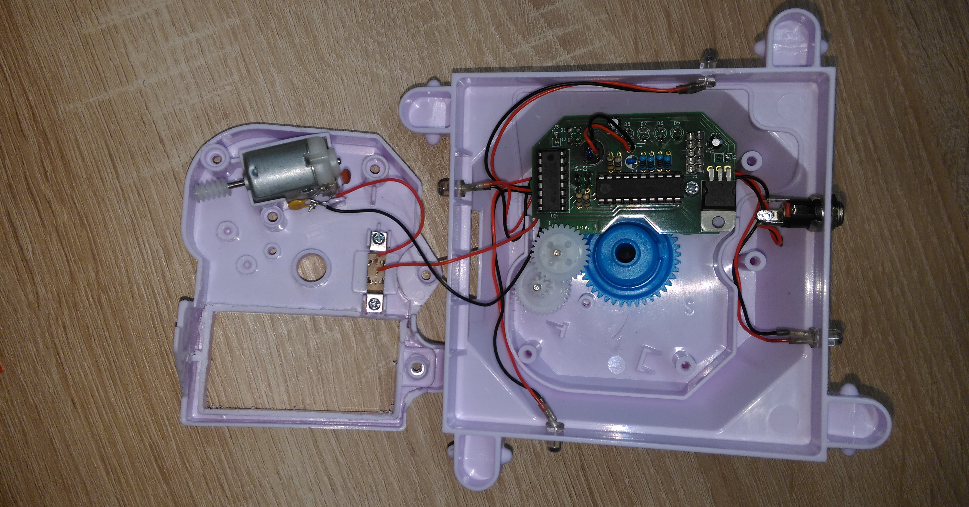
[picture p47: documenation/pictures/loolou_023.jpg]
  	
	\caption{Spielbasis mit eingesetzter Platine}
	\label{fig23}
\end{figure}
\vspace{0.5cm} 

Im Anschluss wird die Unterseite auf die Oberseite gesetzt und die 5 Schrauben der Spielbasis wieder festgeschraubt. Nun sollte man pr"ufen, ob die Spielbasis wieder richtig schlie"st. Sollte beim Vorbereiten der Spielbasis nicht sauber gearbeitet worden sein, dann muss hier nochmals nachgearbeitet werden. Die Spielbasis darf keine Erhebungen aufweisen, ansonsten steht die Spielbasis nicht sicher oder der Arm des Looping Louie kann nicht richtig arretiert werden.
Die Abbildung ~\ref{fig24} zeigt die wieder zusammengebaute Spielbasis ohne Batteriefachabdeckung.

\vspace{0.5cm}
\begin{figure}[!ht]
	\centering
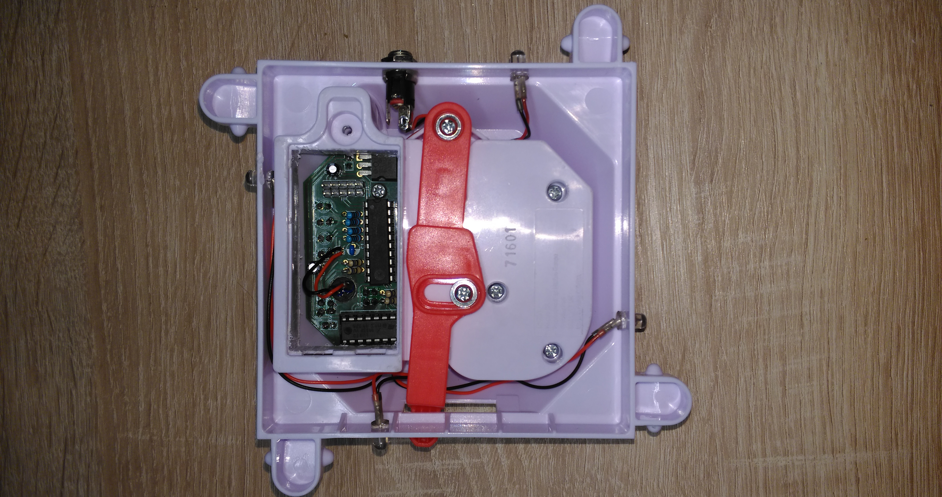
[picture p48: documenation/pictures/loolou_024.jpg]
  	
	\caption{Zusammengebaute Spielbasis ohne Batteriefachabdeckung}
	\label{fig24}
\end{figure}
\vspace{0.5cm} 

In der folgenden Abbildung (Abbildung ~\ref{fig25}) ist die geschlossene Spielbasis von oben und unten zu sehen.

\vspace{1cm}
\begin{figure}[!ht]
	\centering
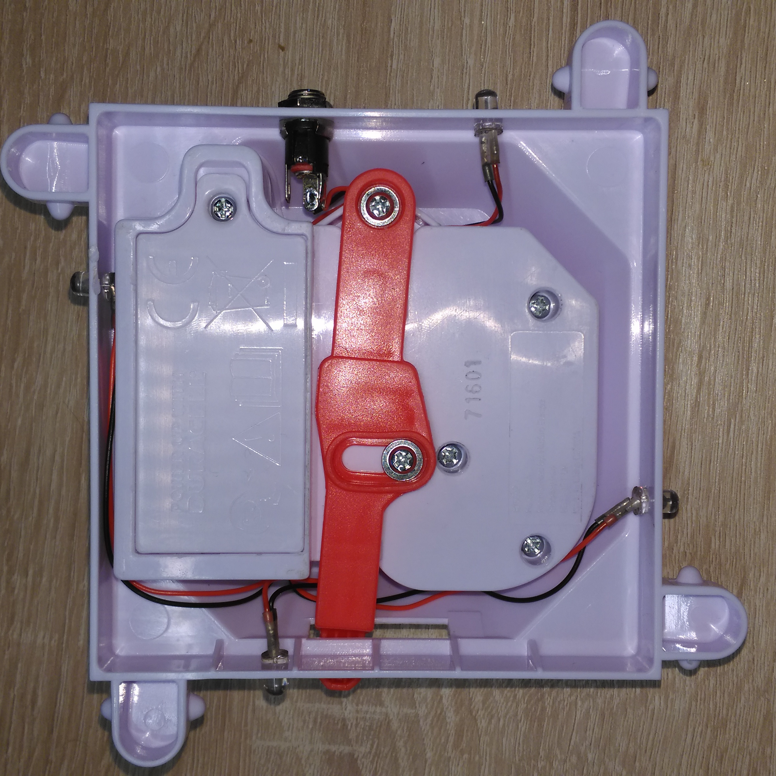
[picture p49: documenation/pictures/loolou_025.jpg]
  	\subfigure[Oberseite]{}
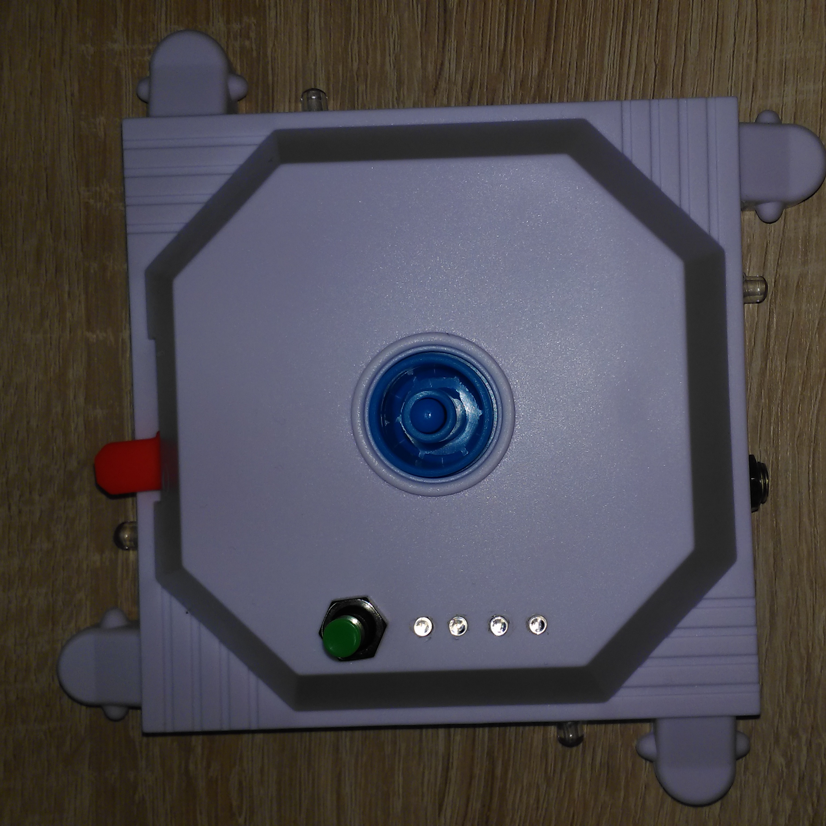
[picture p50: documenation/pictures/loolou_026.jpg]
	\subfigure[Unterseite]{}
	\caption{Platine mit allen Bauteilen}
	\label{fig25}
	%\label{fig23}
\end{figure}
\vspace{0.5cm}

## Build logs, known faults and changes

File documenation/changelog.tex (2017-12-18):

\subsection{Revision 1}
\begin{itemize}
\item Erstellen des Schaltplanes.
\item Erstellen des C-Quellcodes.
\item Erstellen des Platinen-Layouts.
\item Erstellen der Dokumentation.
\item Hinzuf"ugen von Fotos.
\end{itemize}

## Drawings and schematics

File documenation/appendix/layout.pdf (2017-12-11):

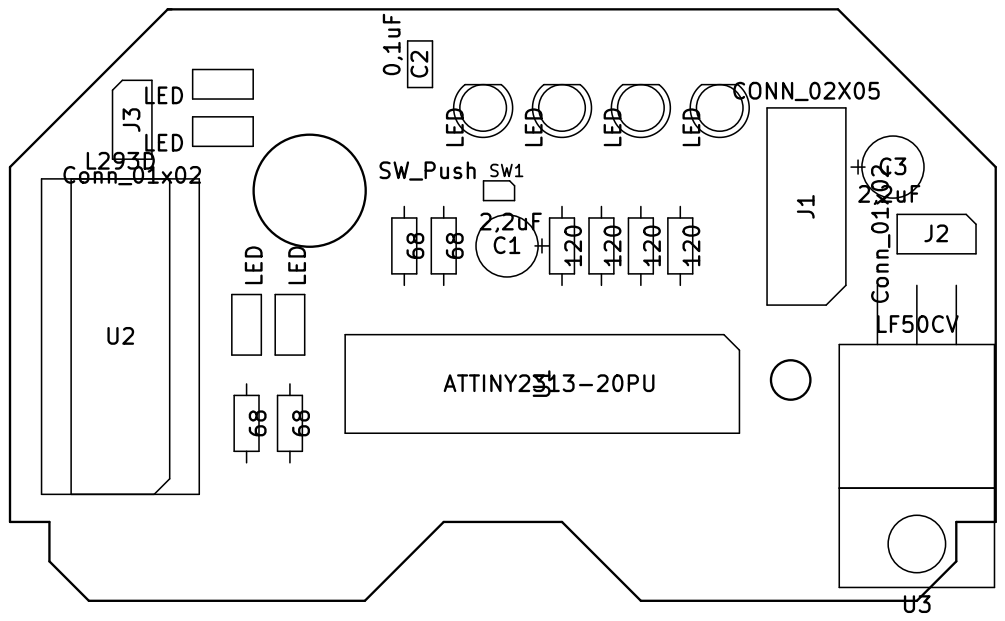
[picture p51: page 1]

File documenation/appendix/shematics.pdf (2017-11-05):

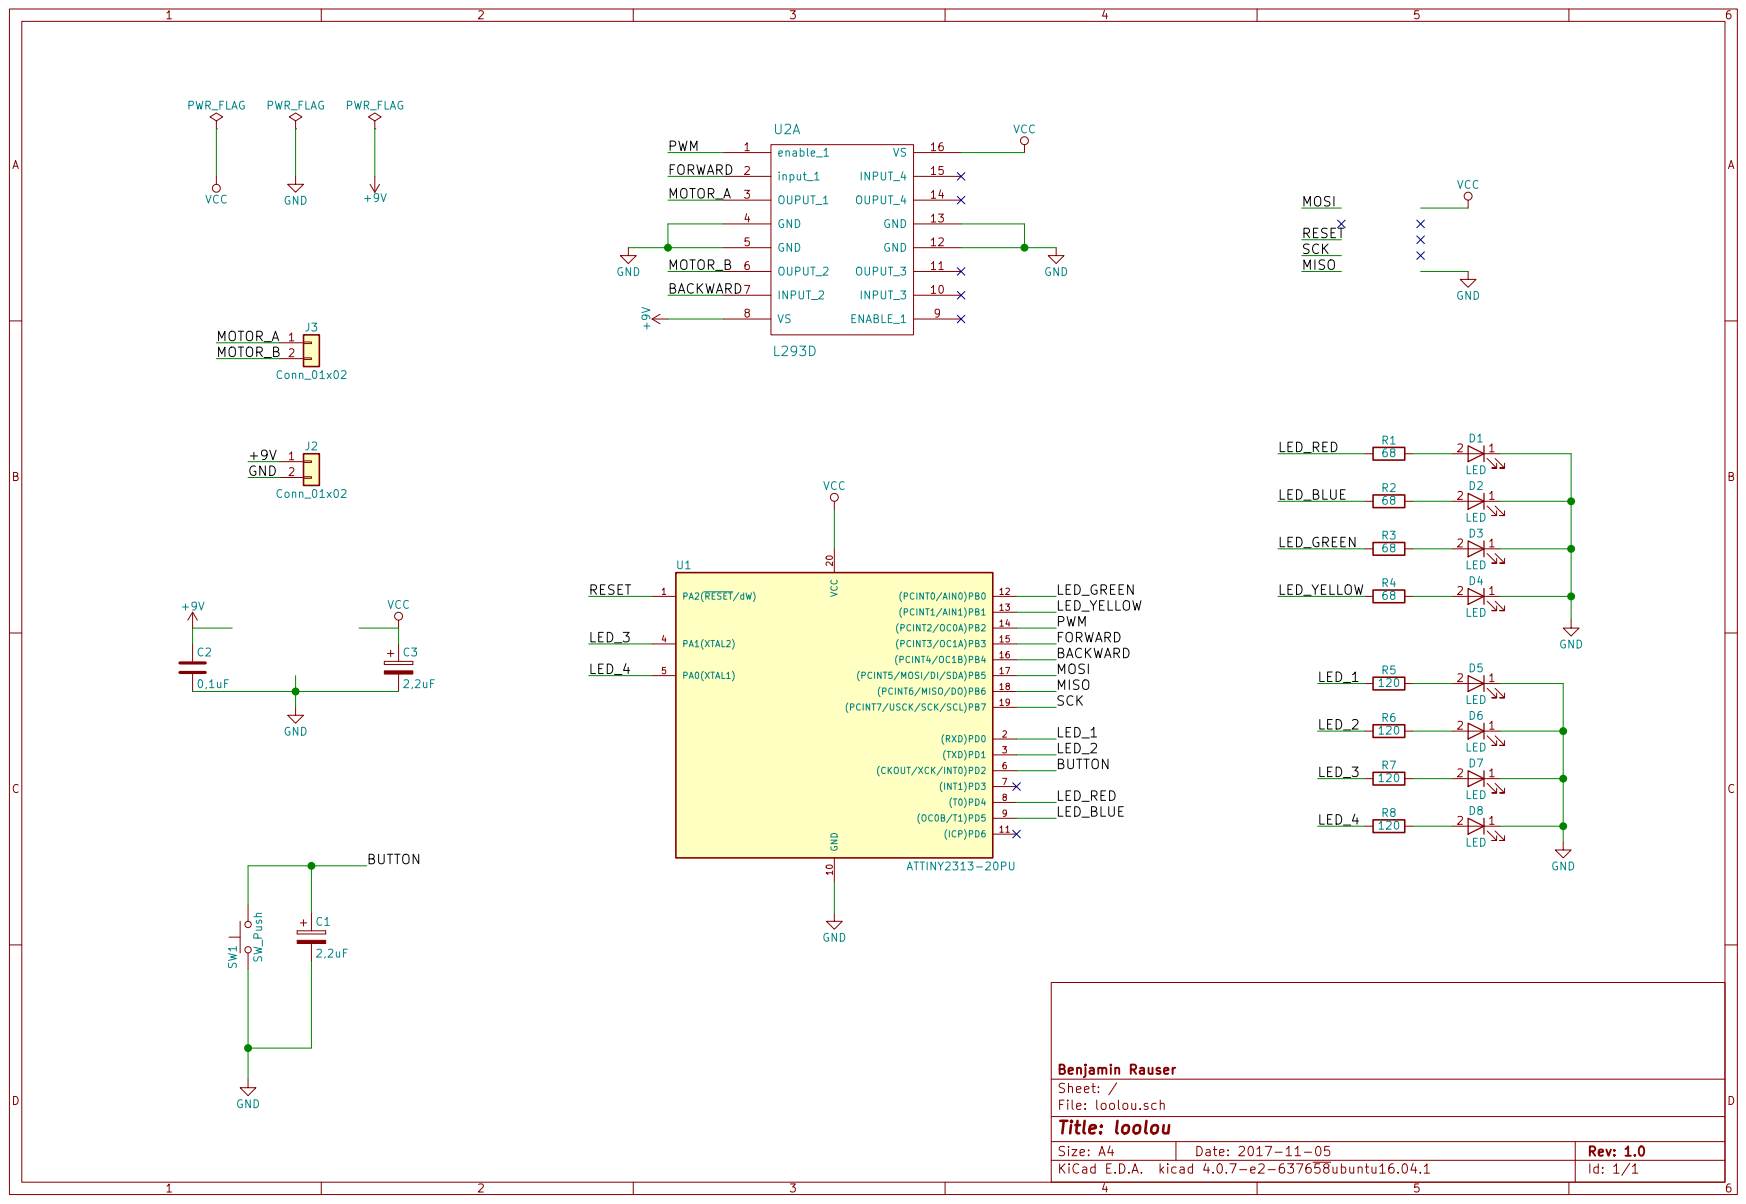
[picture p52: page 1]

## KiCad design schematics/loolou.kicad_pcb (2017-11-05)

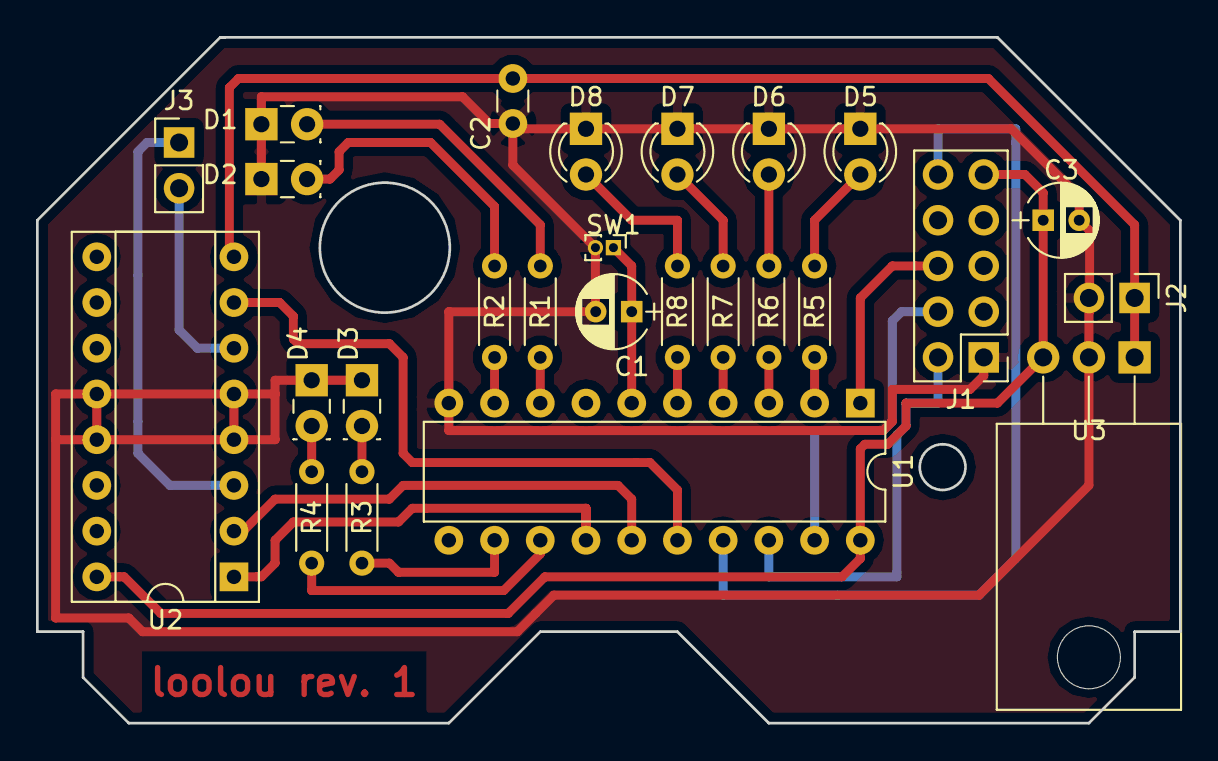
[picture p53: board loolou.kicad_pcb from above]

Board: 2 copper layers, 63.5 x 38.1 mm, 26 parts (0 on the bottom side), 29 nets.

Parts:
C1, C3: 2,2uF; CP_Radial_D4.0mm_P2.00mm
C2: 0,1uF; C_Disc_D3.0mm_W1.6mm_P2.50mm
D1, D2, D3, D4: LED; LED_Rectangular_W3.9mm_H1.9mm
D5, D6, D7, D8: LED; LED_D3.0mm
J1: CONN_02X05; Pin_Header_Straight_2x05_Pitch2.54mm
J2, J3: Conn_01x02; Pin_Header_Straight_1x02_Pitch2.54mm
R1, R2, R3, R4: 68; R_Axial_DIN0204_L3.6mm_D1.6mm_P5.08mm_Horizontal
R5, R6, R7, R8: 120; R_Axial_DIN0204_L3.6mm_D1.6mm_P5.08mm_Horizontal
SW1: SW_Push; Pin_Header_Straight_1x02_Pitch1.00mm
U1: ATTINY2313-20PU; DIP-20_W7.62mm
U2: L293D; DIP-16_W7.62mm_Socket
U3: LF50CV; TO-220_Horizontal

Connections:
+9V: C2.1, J2.1, U2.8, U3.1
/BACKWARD: U1.16, U2.7
/BUTTON: C1.1, SW1.1, U1.6
/FORWARD: U1.15, U2.2
/LED_1: R5.1, U1.2
/LED_2: R6.1, U1.3
/LED_3: R7.1, U1.4
/LED_4: R8.1, U1.5
/LED_BLUE: R2.1, U1.9
/LED_GREEN: R3.1, U1.12
/LED_RED: R1.1, U1.8
/LED_YELLOW: R4.1, U1.13
/MISO: J1.2, U1.18
/MOSI: J1.10, U1.17
/MOTOR_A: J3.1, U2.3
/MOTOR_B: J3.2, U2.6
/PWM: U1.14, U2.1
/RESET: J1.6, U1.1
/SCK: J1.4, U1.19
GND: C1.2, C2.2, C3.2, D1.1, D2.1, D3.1, D4.1, D5.1, D6.1, D7.1, D8.1, J1.1, J2.2, SW1.2, U1.10, U2.4, U2.5, U2.12, U2.13, U3.2
unnamed: D1.2, R1.2
unnamed: D2.2, R2.2
unnamed: D3.2, R3.2
unnamed: D4.2, R4.2
unnamed: D5.2, R5.2
unnamed: D6.2, R6.2
unnamed: D7.2, R7.2
unnamed: D8.2, R8.2
VCC: C3.1, J1.9, U1.20, U2.16, U3.3

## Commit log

2017-10-27 change motor direction to fix the issue on the shematics
    [main.c]
2017-11-05 fix F_CPU value; refactor interrupts/functions (use timer)
    [main.c]
2017-11-05 move set timer to init
2017-11-05 add shematics and templates
    [loolou.kicad_pcb, loolou.sch]
